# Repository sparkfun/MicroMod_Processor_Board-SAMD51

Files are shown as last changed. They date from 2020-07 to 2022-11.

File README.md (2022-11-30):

SparkFun MicroMod SAMD51 Processor
========================================

SparkFun MicroMod SAMD51 Processor (DEV-16791) (https://www.sparkfun.com/products/16791)

[*SparkFun MicroMod SAMD51 Processor (DEV-16791)*](https://www.sparkfun.com/products/16791)

With a 32-bit ARM Cortex-M4F MCU, the SparkFun MicroMod SAMD51 Processor Board is one powerful microcontroller packaged on a small board! The provides you with an economical and easy to use development platform if you're needing more power with minimal working space. This MicroMod SAMD51 even comes flashed with the same convenient UF2 bootloader like the SAMD51 Thing Plus and the RedBoard Turbo. The MicroMod SAMD51 uses the MicroMod Hardware pinout to easily switch between carrier boards.

The ATSAMD51J20 utilizes a 32-bit ARM Cortex-M4 processor with Floating Point Unit (FPU), running up to 120MHz, up to 1MB of flash memory, up to 256KB of SRAM with ECC, up to 6 SERCOM interfaces, and other features.

Repository Contents
-------------------

* **/Arduino Board Files** - Board definitions for MicroMod SAMD51
* **/Documentation** - Datasheets, additional product information
* **/Hardware** - Eagle design files (.brd, .sch)
* **/Production** - Production panel files (.brd)
* **/uf2-bootloader** - Default firmware

Documentation
--------------
* **[Graphical Datasheet](https://github.com/sparkfun/Graphical_Datasheets/tree/main/Datasheets/SAM51)** - Pinout of the SAMD51 Processor Board
* **[Installing Board Definitions in the Arduino IDE](https://learn.sparkfun.com/tutorials/installing-board-definitions-in-the-arduino-ide)** - Information about installing Arduino Board Files for Arduino
* **[Hookup Guide](https://learn.sparkfun.com/tutorials/micromod-samd51-processor-board-hookup-guide)** - Basic hookup guide

Product Versions
----------------
* [DEV-16791](https://www.sparkfun.com/products/16791)

Version History
---------------
* [v1.3](https://github.com/sparkfun/MicroMod_Processor_Board-SAMD51/tree/v1.3) - Minor update to swap SPI1 lines to the external flash
* [v1.2](https://github.com/sparkfun/MicroMod_Processor_Board-SAMD51/tree/v1.2) - Initial Release 

License Information
-------------------

This product is _**open source**_! 

Please review the LICENSE.md file for license information. 

If you have any questions or concerns on licensing, please contact technical support on our [SparkFun forums](https://forum.sparkfun.com/viewforum.php?f=152).

Distributed as-is; no warranty is given.

- Your friends at SparkFun.

_<COLLABORATION CREDIT>_

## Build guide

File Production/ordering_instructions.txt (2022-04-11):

panel size, 194x70mm
PCB thickness, 0.8mm
number of layers, 4
soldermask color, Red
silkscreen color, White
oz copper, 1oz
finish, ENIG
stencils, top+bottom
pcs per panel, 16
min trace width, 0.1016mm / 0.0040in
min drill size, 0.2000mm / 0.0079in
filename to layer stackup 1/2/3/4: GTL, GL2, GL3, GBL

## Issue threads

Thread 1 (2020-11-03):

Add General/Bus pin definitions to variant.h

adamgarbo, 2020-11-03:
### Subject of the issue
To the best of my knowledge, the SAMD51 Processor board definition appears to be missing (at least) all General/Bus pin definitions in its `variant.h` file.

### Your workbench
* What development board or microcontroller are you using?
  * MicroMod SAMD51 Processor
* What version of hardware or breakout board are you using?
  * MicroMod Data Logging Carrier Board (MMDLCB)
* How is everything being powered?
  * USB-C

### Steps to reproduce
* Connect the SAMD51 Processor to the Data Logging Carrier Board and attempt to compile the MMDLCB Peripheral_Power_Control example:
https://github.com/sparkfun/MicroMod_Data_Logging_Carrier/blob/master/Examples/Peripheral_Power_Control/Peripheral_Power_Control.ino

### Expected behavior
Code should compile as normal.

### Actual behavior
```
Peripheral_Power_Control:5:16: error: 'G0' was not declared in this scope
 int headerCS = G0;
                ^
Peripheral_Power_Control:6:30: error: 'G1' was not declared in this scope
 int peripheralPowerControl = G1;
                              ^
Peripheral_Power_Control:7:25: error: 'G2' was not declared in this scope
 int qwiicPowerControl = G2;
                         ^
exit status 1
```

While I've been able to determine the physical pin numbers on the SAMD51 of G0/G1/G2 power control pins, referencing them directly doesn't work. I believe this most likely has something to do with the SAMD51 being multiplexed.

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

adamgarbo, 2020-11-03:
Ah, of course, I figure it out immediately after! I see now in the schematic how the pins are related: G0/D2, G1/D3, G2/D4
Using these pin definitions, I'm able to control the G1/G2 regulators on the MMDLCB directly.

The question is, should all of the "G"s be included in the variant.h file, or should users simply use their digital pin equivalents? For example, the Artemis variant.h file has all of the General/Bus pins defined. I suppose consistency is key!

```
#define G0 16
#define G1 33
#define G2 34
#define G3 27
#define G4 28
#define G5 29
#define G6 14
#define G7 15
#define G8 3
#define G9 ADC_DIFF_NEG
#define G10 ADC_DIFF_POS
#define G11 11
```

Cheers,
Adam

edspark, 2020-11-04:
Ah this is a great idea, something I had considered and not sure why I didn't do. Thanks for bringing it back to my attention - I'll roll it into a release soon.

edspark, 2020-11-04:
Thanks for the issue, the `#defines` for the relevant pins on the SAMD51 Micromod have been added to our Arduino Boards repository. I did not add ADC related `#defines` as they are not physically routed in such a way on the SAMD51 Micromod. I've also added keywords to that repository so that they're highlighted when you use the general pin nomenclature: `G0`, `G1`, etc... You can find these changes in the [1.7.8 release](https://github.com/sparkfun/Arduino_Boards/commit/cf6146e5421a28d8b91430474607ebbde78a0eef).

Closed 2020-11-04.

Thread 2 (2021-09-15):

Swapped SPI1 lines

shale-bridge, 2021-09-15:
### Swapped SPI1 lines
External W25Q128 flash CIPO/COPI lines are swapped, so flash is unusable with SPI.

### Equipment
* SAMD51 MicroMod v1.2
* ATP (All-The-Pins) v1.1 breakout
* Custom motherboard

### Workaround
Swapping the CIPO/COPI lines in software and manually (bit-banging) data to/from the flash chip.

edspark, 2021-09-15:
Thanks for the issue, a fix is on the way. I'll update in a few weeks when the new version is ready. When that happens feel free to reach out to SparkFun's customer service to get a replacement.

stonehippo, 2021-11-10:
Any update on this @edspark? Would love to get a board with working external flash.

shale-bridge, 2021-11-10:
Looks like all SAMD51 chips are on backorder until well into next year (Estimates at Nov/Dec 2022 before any stock becomes available).

shale-bridge, 2021-11-10:
@stonehippo If you already have a SAMD51 MicroMod, I made a library that works with the layout error through software bit-banging.

[SAMD51 Bit Bang Library](https://github.com/shale-bridge/samd51-micromod-bitbang)

stonehippo, 2021-11-10:
Thanks, @shale-bridge, I saw that, and I’ll probably use it for Arduino until we can get updated boards.

I had ported CircuitPython to this board, but not having the external flash makes that sorta nasty. I was going to look into making a personal patch to try using your idea to enable bitbang serial for this board there, too.

edspark, 2021-11-10:
Hello everyone, yes it took a bit longer for the boards to arrive but they're expected sometime this week. After they received it will take a week or two to get back on storefront.

stonehippo, 2021-12-01:
@edspark I got a back in stock notification on the module (though the site is still showing it as backorder). Has the new version arrived? If so, what's the best way to exchange the previous version?

edspark, 2021-12-07:
Hey @stonehippo, I do see we have the PCBs in stock and I'm currently inquiring as to when they will be moved through production to get them back onto the website. The best way is to exchange your old one is go through the process [listed here](https://www.sparkfun.com/returns).

edspark, 2022-04-11:
I've finally merged in the latest branch with the fix. I've tested the lines using [SparkFun's SPI SerialFlash library](https://github.com/sparkfun/SparkFun_SPI_SerialFlash_Arduino_Library) and I can now finally close this issue.

stonehippo, 2022-04-11:
@edspark could you share the test code you used? I want to jump on fixing the support in CircuitPython and that will help.

edspark, 2022-04-12:
Example here in the SparkFun SPI SerialFlash Library:
https://github.com/sparkfun/SparkFun_SPI_SerialFlash_Arduino_Library/blob/main/examples/SPI_Flash_Example/SPI_Flash_Example.ino

stonehippo, 2022-04-12:
Thanks, I was hoping for the exact changes you made to that example (i.e. did you need to set the HOLD and WP pins high, and what pins did you use, etc). If you used it as-is, great!

stonehippo, 2022-04-12:
Thanks!

stonehippo, 2022-04-19:
Thanks for the support, @edspark! I was able finally able to get the flash working with Circuitpython.

Closed 2022-04-11.

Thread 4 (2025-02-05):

Self-build binary for 'sparkfun-samd51-micromod' is not working

walx666, 2025-02-05:
It is possible to build the bootloader-binary for the 'sparkfun-samd51-micromod' board, but the bootloader-binary is not working!

I was not able to build a working bootloader-binary with the latest sources from
https://github.com/adafruit/uf2-samdx1 or https://github.com/microsoft/uf2-samdx1
nor any older commit i tried…

...also tried to build the bootloader with the commit 'df89a1f', but that seems to not have the changes you may made (dirty build).

I also have an 'sparkfun-samd51-thingplus' and was able to build a working bootloader with the same evnrionment.

## Symptoms
The LED is not flashing as it should and the usb-flashdrive nor the CDC-device is not appearing in the os (windows in my case)

## Hardware
- micromod-atp
- sparkfun-samd51-micromod (ATSAMD51J20A with chip revision A and D)
- sparkfun-samd51-thingplus

## Build Evnrionment:
- windows 11 pro 24H2
	- arm-none-eabi-gcc.exe (GNU Arm Embedded Toolchain 10.3-2021.10) 10.3.1 20210824 (release)
- debian12 (wsl)
	- arm-none-eabi-gcc (GNU Arm Embedded Toolchain 10.3-2021.10) 10.3.1 20210824 (release)

---

The board has this INFO_UF2.TXT (only as binary and board-definition avaliable):
```
UF2 Bootloader v3.4.0-65-gdf89a1f-dirty SFHWRO
Model: SparkFun MicroMod SAMD51
Board-ID: SAMD51J20A-SparkFun-MicroMod
```

I've made a board, that integrates the 'sparkfun-samd51-micromod' board - so i'd like to have the improvements of a newer build / release, beacuse sometimes the flash gets corrupted or the board does not start after powerup (see https://github.com/adafruit/uf2-samdx1/issues/217) -
also i want to make little changes to the bootloader for my needs.

So please let me know, what you have changed to the bootloader code or board-definition, so that it works - or release a working codebase.

Best would be to fork the uf2-samdx1 and release it for the public - or even better upstream the changes.

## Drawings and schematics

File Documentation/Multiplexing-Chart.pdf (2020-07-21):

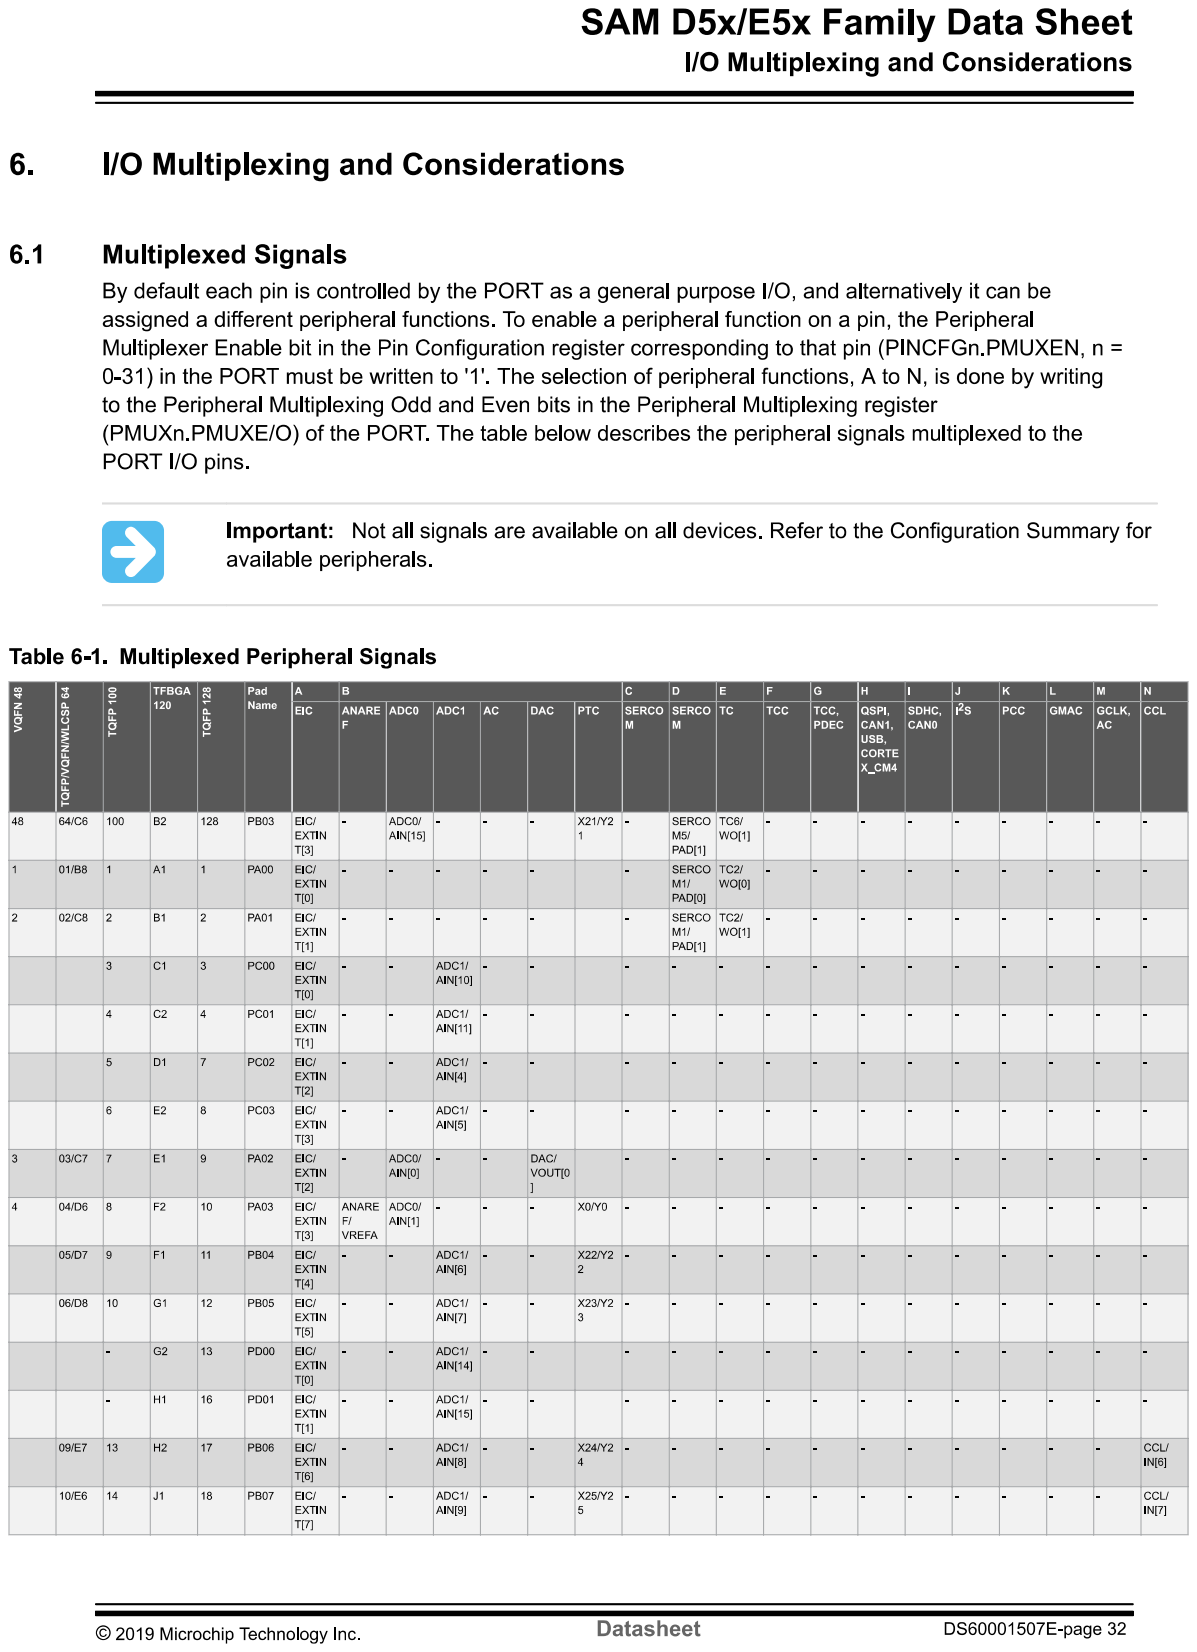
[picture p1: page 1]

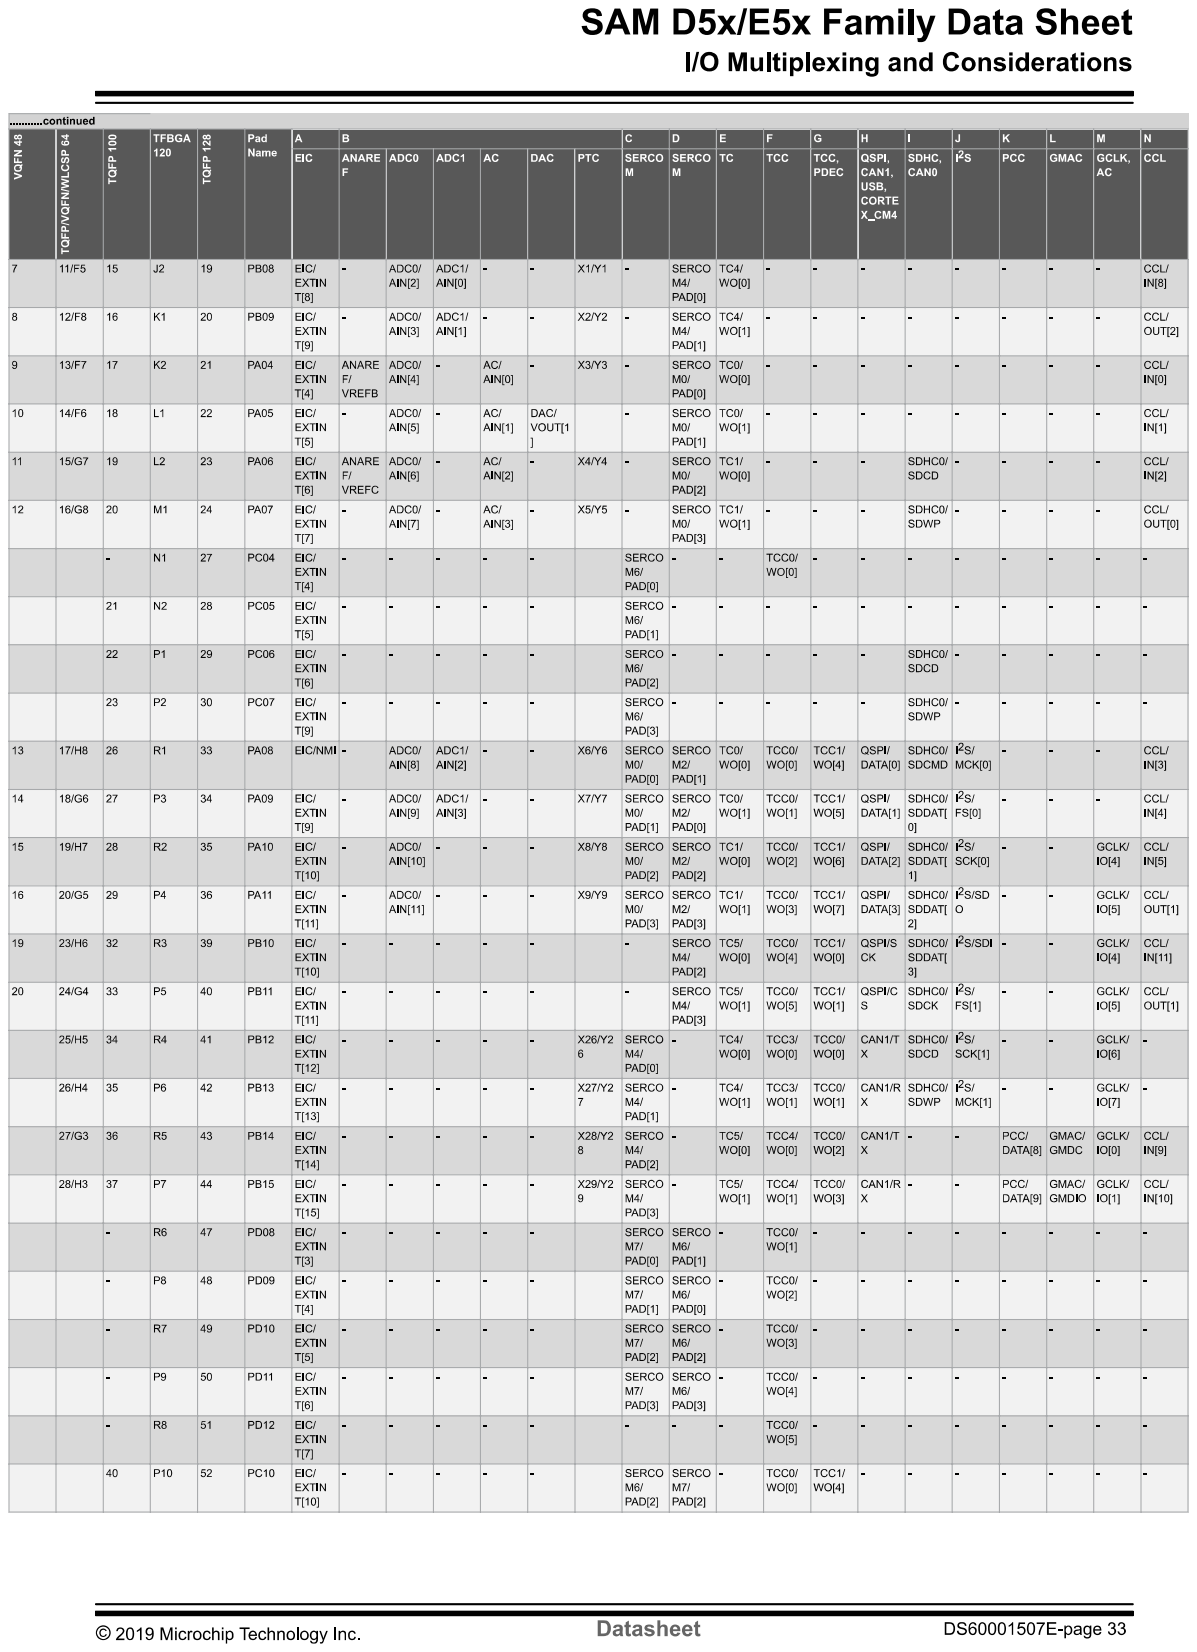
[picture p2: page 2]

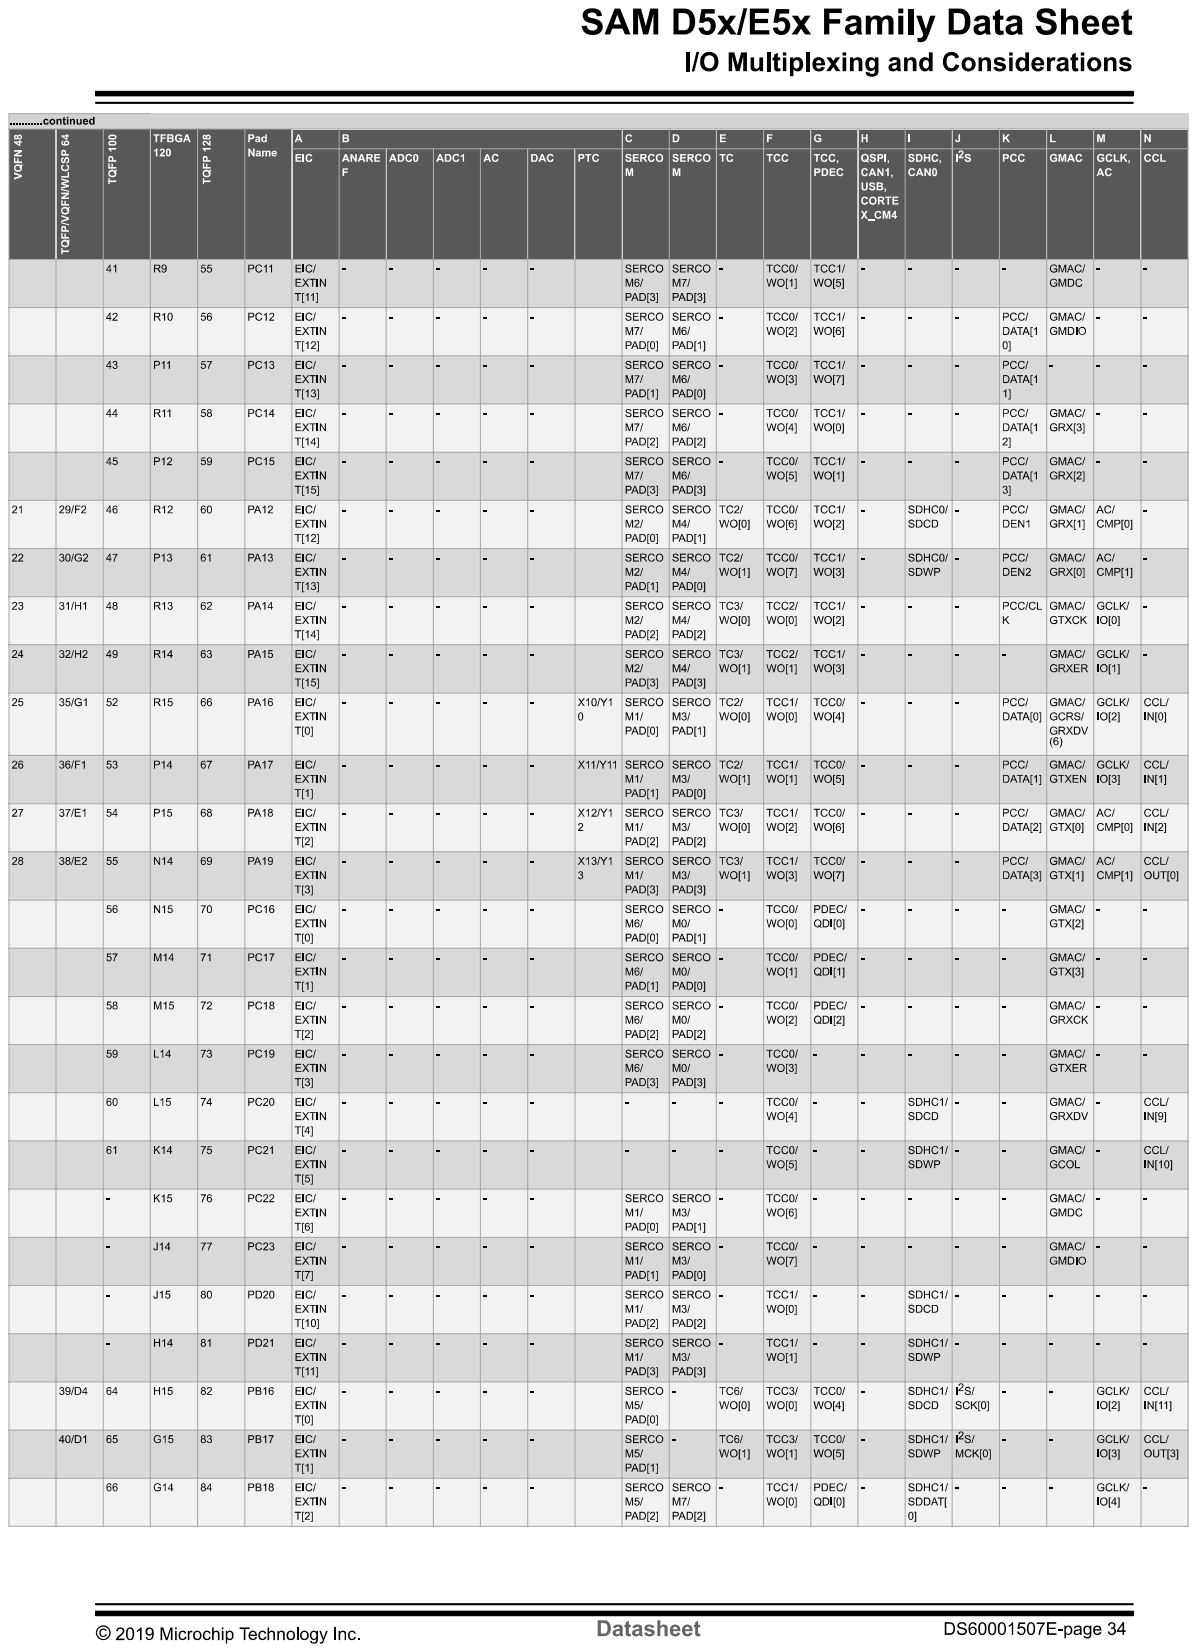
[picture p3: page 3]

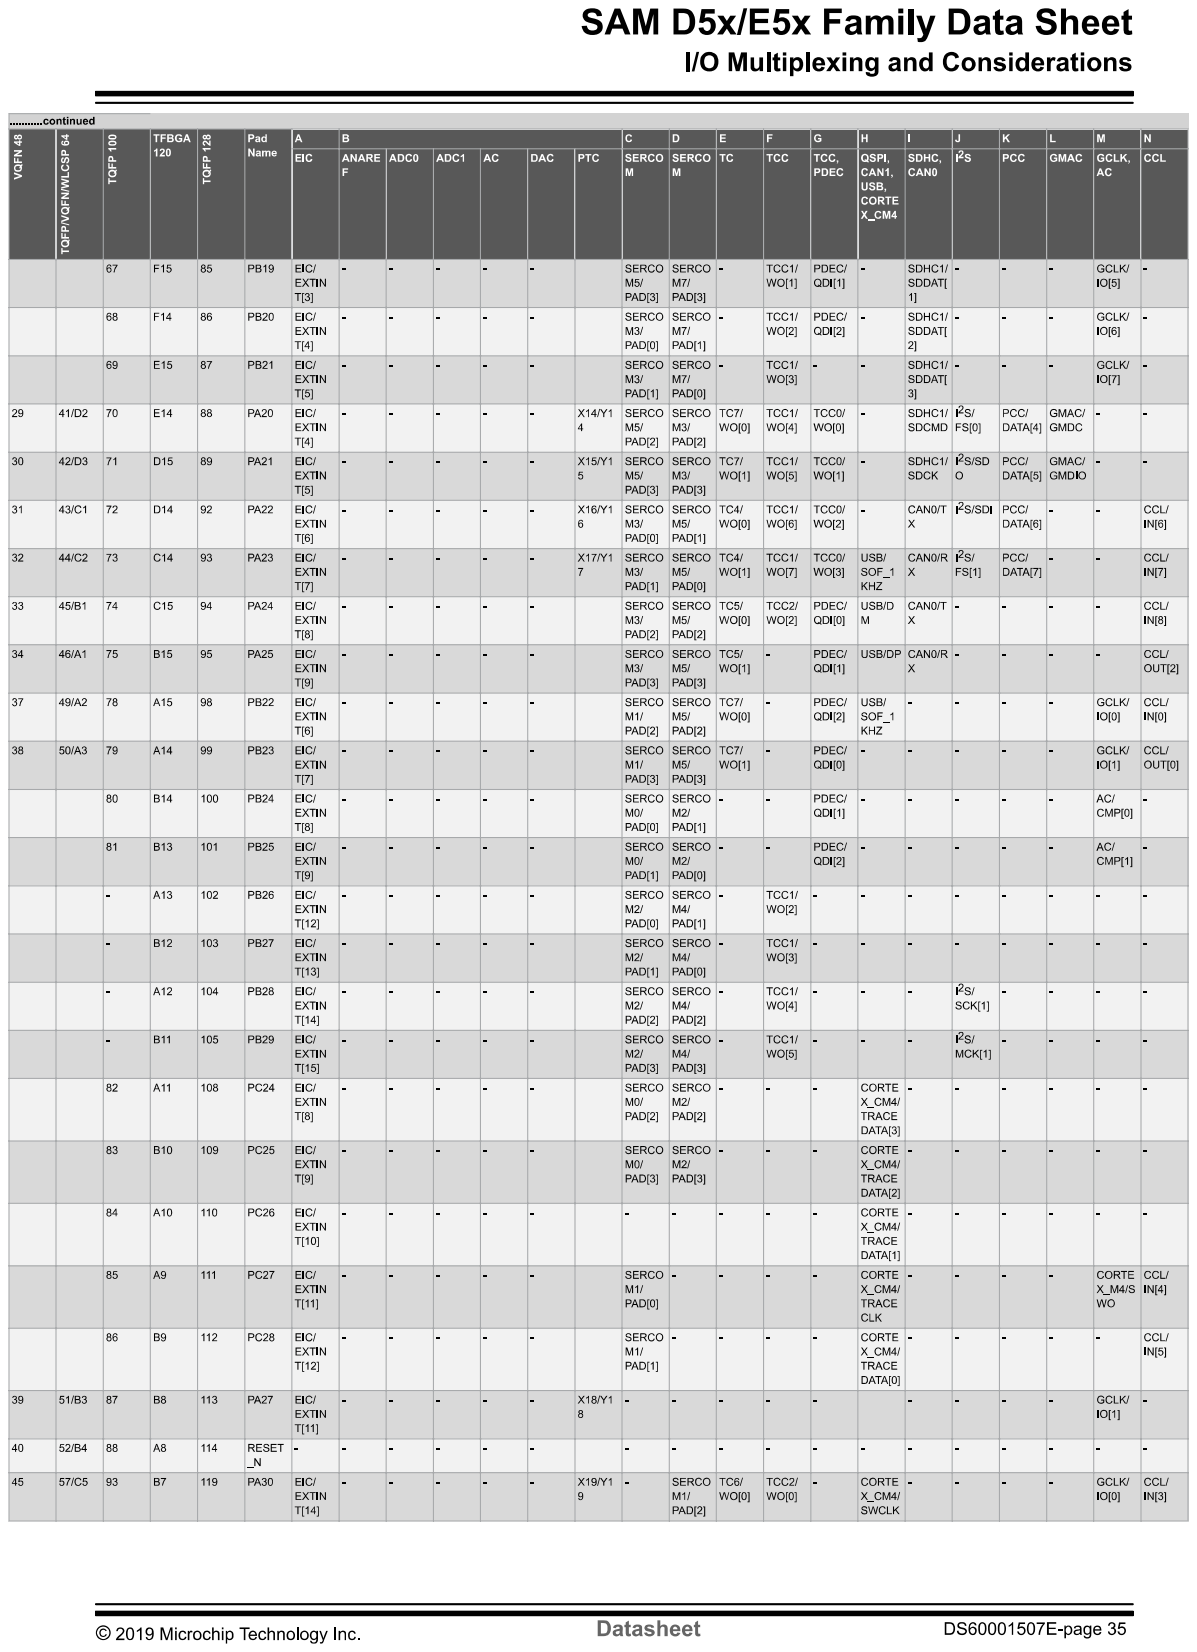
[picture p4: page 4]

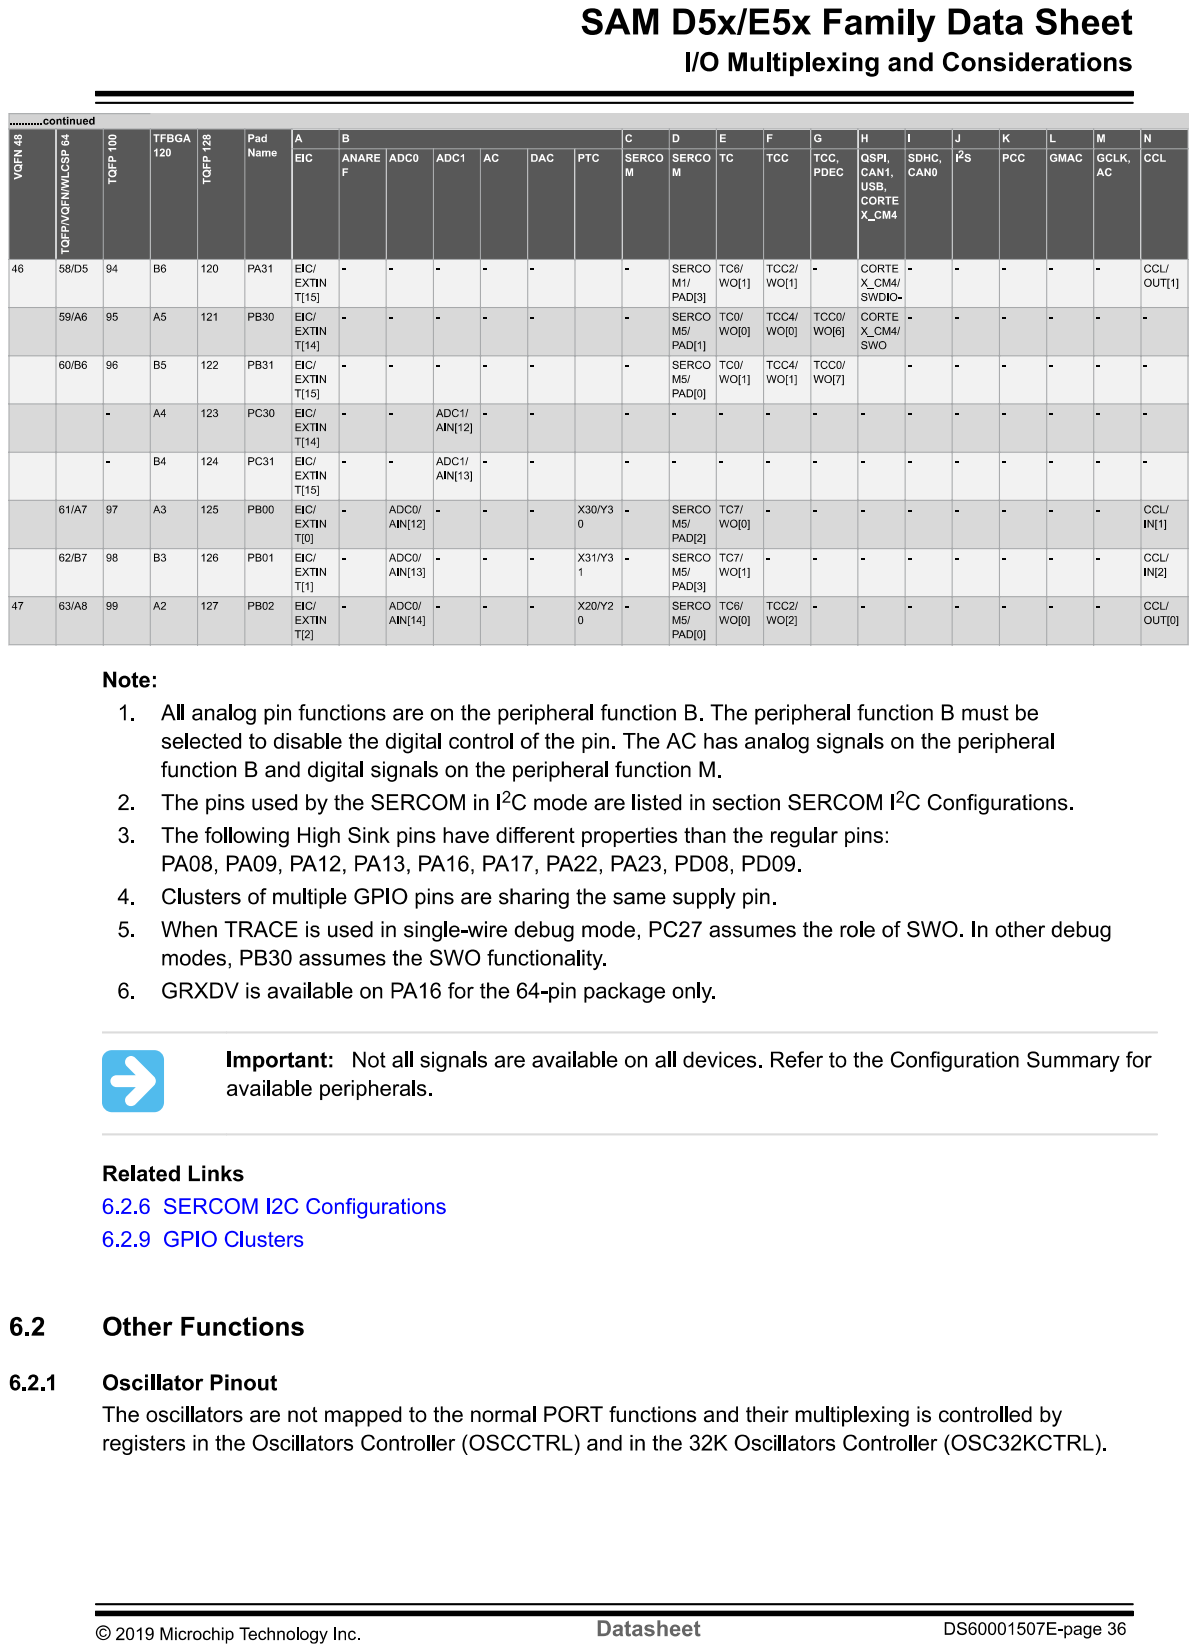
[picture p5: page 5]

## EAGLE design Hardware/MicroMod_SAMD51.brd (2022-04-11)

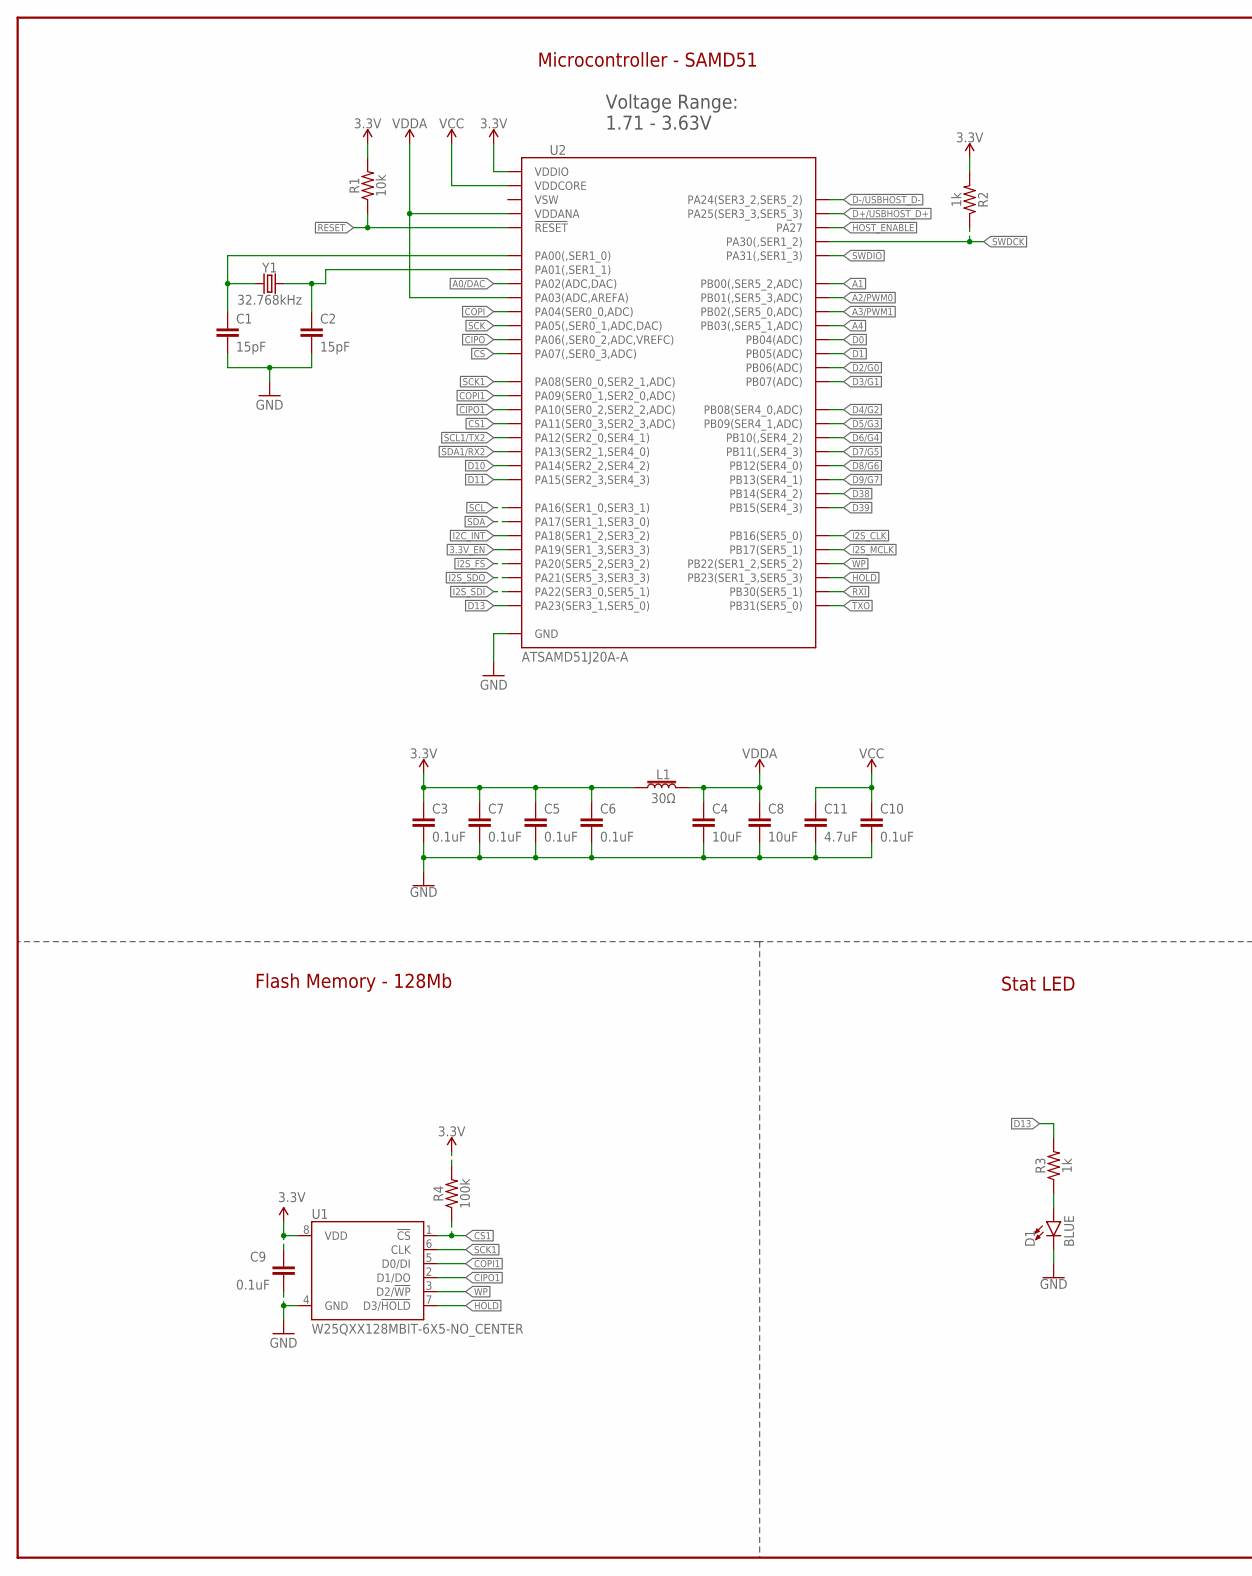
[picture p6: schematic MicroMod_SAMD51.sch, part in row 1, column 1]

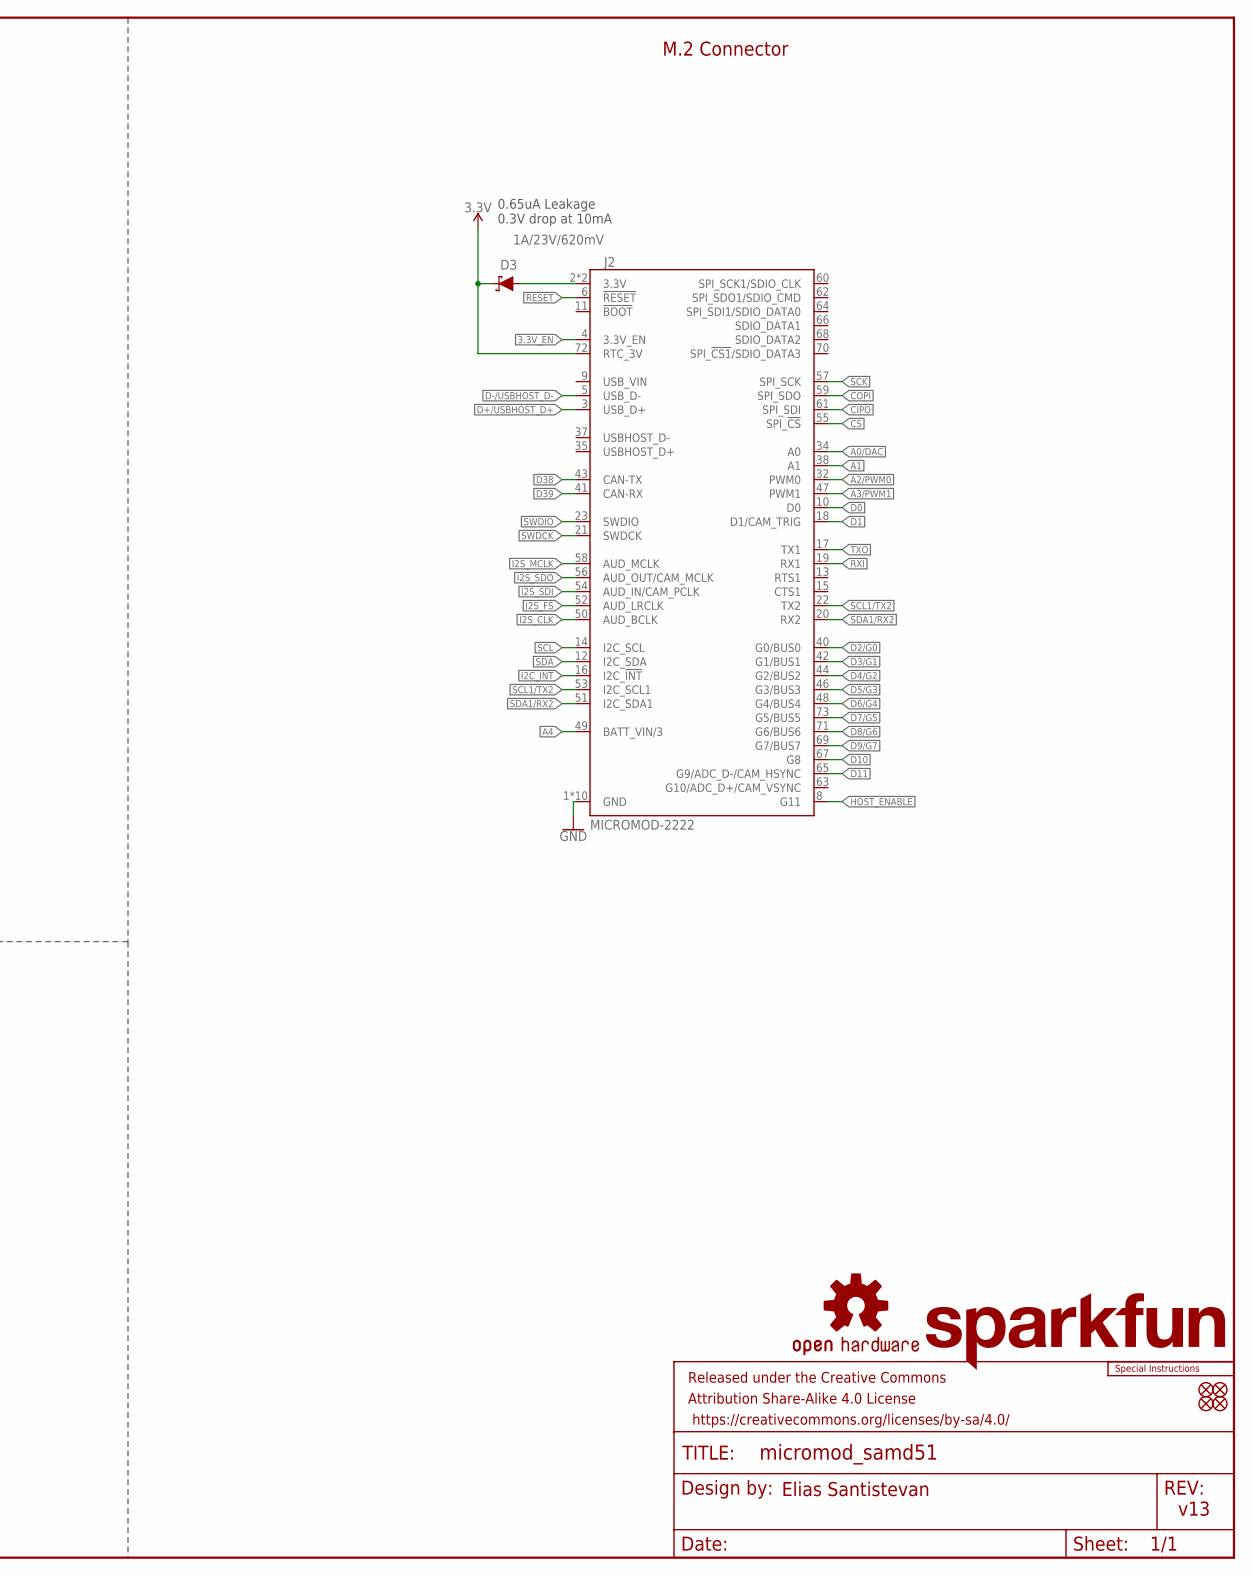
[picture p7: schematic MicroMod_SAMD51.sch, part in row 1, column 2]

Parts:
C1, C2: 15pF; 0402-TIGHT
C3, C5, C6, C7, C9, C10: 0.1uF; 0402-TIGHT
C4, C8: 10uF; 0402-TIGHT
C11: 4.7uF; 0402-TIGHT
D1: BLUE; LED-0603
D3: 1A/23V/620mV; SOD-323
FD5, FD6, FD7, FD8: FIDUCIALUFIDUCIAL; FIDUCIAL-MICRO
FRAME2: FRAME-LEDGER; CREATIVE_COMMONS
J2: MICROMOD-2222; M.2-CARD-E-22
L1: 30Ω; 0402-TIGHT
LOGO2: OSHW-LOGOMINI; OSHW-LOGO-MINI
LOGO5: SPECIAL_INSTRUCTIONS-ORDERING; ORDERING_INSTRUCTIONS
LOGO6: SFE_LOGO_NAME.1_INCH; SFE_LOGO_NAME_.1
R1: 10k; 0402-TIGHT
R2, R3: 1k; 0402-TIGHT
R4: 100k; 0402-TIGHT
U1: W25QXX128MBIT-6X5-NO_CENTER; WSON-8-6X5-NO_CENTERPAD
U2: ATSAMD51J20A-A; TQFP64
Y1: 32.768kHz; CRYSTAL-SMD-3.2X1.5MM

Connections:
3.3V: C3.1, C5.1, C6.1, C7.1, C9.1, D3.C, J2.72 (RTC_3V), L1.1, R1.2, R2.2, R4.2, U1.8 (VDD), U2.21 (VDDIO), U2.34 (VDDIO), U2.48 (VDDIO), U2.56 (VDDIO)
3.3V_EN: J2.4 (3.3V_EN), U2.38 (PA19(SER1_3,SER3_3))
3.3V_IN: D3.A, J2.2 (3.3V), J2.74 (3.3V)
!CS: J2.55 (SPI_!CS!), U2.16 (PA07(,SER0_3,ADC))
!CS1!: R4.1, U1.1 (!CS!), U2.20 (PA11(SER0_3,SER2_3,ADC))
!HOLD!: U1.7 (D3/!HOLD!), U2.50 (PB23(SER1_3,SER5_3))
!RESET: J2.6 (!RESET!), R1.1, U2.52 (!RESET)
!WP!: U1.3 (D2/!WP!), U2.49 (PB22(SER1_2,SER5_2))
A0/DAC: J2.34 (A0), U2.3 (PA02(ADC,DAC))
A1: J2.38 (A1), U2.61 (PB00(,SER5_2,ADC))
A2/PWM0: J2.32 (PWM0), U2.62 (PB01(,SER5_3,ADC))
A3/PWM1: J2.47 (PWM1), U2.63 (PB02(,SER5_0,ADC))
A4: J2.49 (BATT_VIN/3), U2.64 (PB03(,SER5_1,ADC))
CIPO: J2.61 (SPI_SDI), U2.15 (PA06(,SER0_2,ADC,VREFC))
CIPO1: U1.2 (D1/DO), U2.19 (PA10(SER0_2,SER2_2,ADC))
COPI: J2.59 (SPI_SDO), U2.13 (PA04(SER0_0,ADC))
COPI1: U1.5 (D0/DI), U2.18 (PA09(SER0_1,SER2_0,ADC))
D0: J2.10 (D0), U2.5 (PB04(ADC))
D1: J2.18 (D1/CAM_TRIG), U2.6 (PB05(ADC))
D2/G0: J2.40 (G0/BUS0), U2.9 (PB06(ADC))
D3/G1: J2.42 (G1/BUS1), U2.10 (PB07(ADC))
D4/G2: J2.44 (G2/BUS2), U2.11 (PB08(SER4_0,ADC))
D5/G3: J2.46 (G3/BUS3), U2.12 (PB09(SER4_1,ADC))
D6/G4: J2.48 (G4/BUS4), U2.23 (PB10(,SER4_2))
D7/G5: J2.73 (G5/BUS5), U2.24 (PB11(,SER4_3))
D8/G6: J2.71 (G6/BUS6), U2.25 (PB12(SER4_0))
D9/G7: J2.69 (G7/BUS7), U2.26 (PB13(SER4_1))
D10: J2.67 (G8), U2.31 (PA14(SER2_2,SER4_2))
D11: J2.65 (G9/ADC_D-/CAM_HSYNC), U2.32 (PA15(SER2_3,SER4_3))
D13: R3.2, U2.44 (PA23(SER3_1,SER5_0))
D38: J2.43 (CAN-TX), U2.27 (PB14(SER4_2))
D39: J2.41 (CAN-RX), U2.28 (PB15(SER4_3))
D+/USBHOST_D+: J2.3 (USB_D+), U2.46 (PA25(SER3_3,SER5_3))
D-/USBHOST_D-: J2.5 (USB_D-), U2.45 (PA24(SER3_2,SER5_2))
GND: C1.2, C2.2, C3.2, C4.2, C5.2, C6.2, C7.2, C8.2, C9.2, C10.2, C11.2, D1.C, J2.1 (GND), J2.7 (GND), J2.33 (GND), J2.36 (GND), J2.39 (GND), J2.45 (GND), J2.75 (GND), J2.GND1 (GND), J2.GND2 (GND), J2.GND3 (GND), U1.4 (GND), U2.7 (GND), U2.22 (GND), U2.33 (GND), U2.47 (GND), U2.54 (GND)
HOST_ENABLE: J2.8 (G11), U2.51 (PA27)
I2C_!INT!: J2.16 (I2C_!INT!), U2.37 (PA18(SER1_2,SER3_2))
I2S_CLK: J2.50 (AUD_BCLK), U2.39 (PB16(SER5_0))
I2S_FS: J2.52 (AUD_LRCLK), U2.41 (PA20(SER5_2,SER3_2))
I2S_MCLK: J2.58 (AUD_MCLK), U2.40 (PB17(SER5_1))
I2S_SDI: J2.54 (AUD_IN/CAM_PCLK), U2.43 (PA22(SER3_0,SER5_1))
I2S_SDO: J2.56 (AUD_OUT/CAM_MCLK), U2.42 (PA21(SER5_3,SER3_3))
unnamed: D1.A, R3.1
RXI: J2.19 (RX1), U2.59 (PB30(SER5_1))
SCK: J2.57 (SPI_SCK), U2.14 (PA05(,SER0_1,ADC,DAC))
SCK1: U1.6 (CLK), U2.17 (PA08(SER0_0,SER2_1,ADC))
SCL: J2.14 (I2C_SCL), U2.35 (PA16(SER1_0,SER3_1))
SCL1/TX2: J2.22 (TX2), J2.53 (I2C_SCL1), U2.29 (PA12(SER2_0,SER4_1))
SDA: J2.12 (I2C_SDA), U2.36 (PA17(SER1_1,SER3_0))
SDA1/RX2: J2.20 (RX2), J2.51 (I2C_SDA1), U2.30 (PA13(SER2_1,SER4_0))
SWDCK: J2.21 (SWDCK), R2.1, U2.57 (PA30(,SER1_2))
SWDIO: J2.23 (SWDIO), U2.58 (PA31(,SER1_3))
TXO: J2.17 (TX1), U2.60 (PB31(SER5_0))
VCC: C10.1, C11.1, U2.53 (VDDCORE)
VDDA: C4.1, C8.1, L1.2, U2.4 (PA03(ADC,AREFA)), U2.8 (VDDANA)
XIN32: C1.1, U2.1 (PA00(,SER1_0)), Y1.P$1 (1)
XOUT32: C2.1, U2.2 (PA01(,SER1_1)), Y1.P$2 (2)

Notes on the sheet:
v13
M.2 Connector
Microcontroller - SAMD51
Flash Memory - 128Mb
Stat LED
Elias Santistevan
0.65uA Leakage 0.3V drop at 10mA
Voltage Range: 1.71 - 3.63V

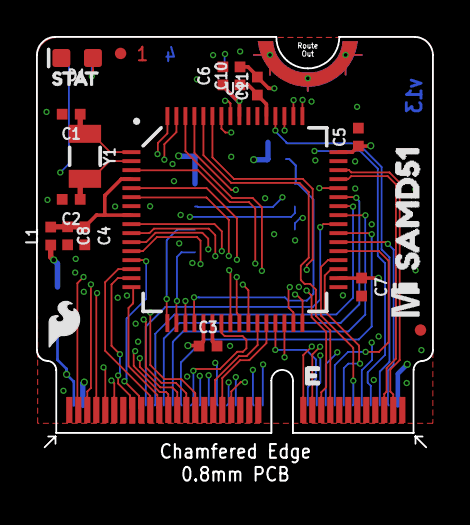
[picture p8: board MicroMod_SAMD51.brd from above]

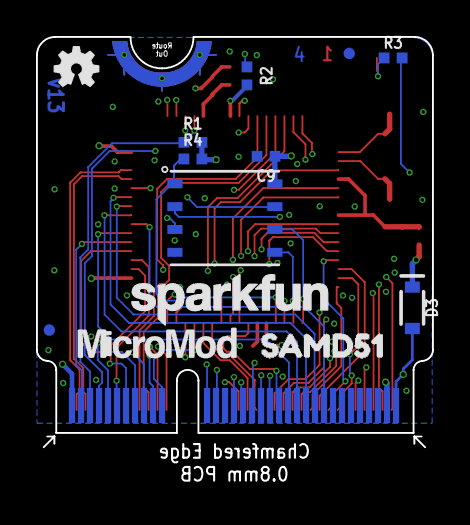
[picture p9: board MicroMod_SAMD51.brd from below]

Board: 4 copper layers, 22.0 x 22.8 mm, 36 parts (13 on the bottom side), 57 nets.

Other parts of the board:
U$1: MICROMOD_MI_LOGO_.35
U$4: MICROMOD_LOGO_.35
U$5, U$6: SAMD510
U$7: SFE_LOGO_FLAME_.1
U$8: STAT0

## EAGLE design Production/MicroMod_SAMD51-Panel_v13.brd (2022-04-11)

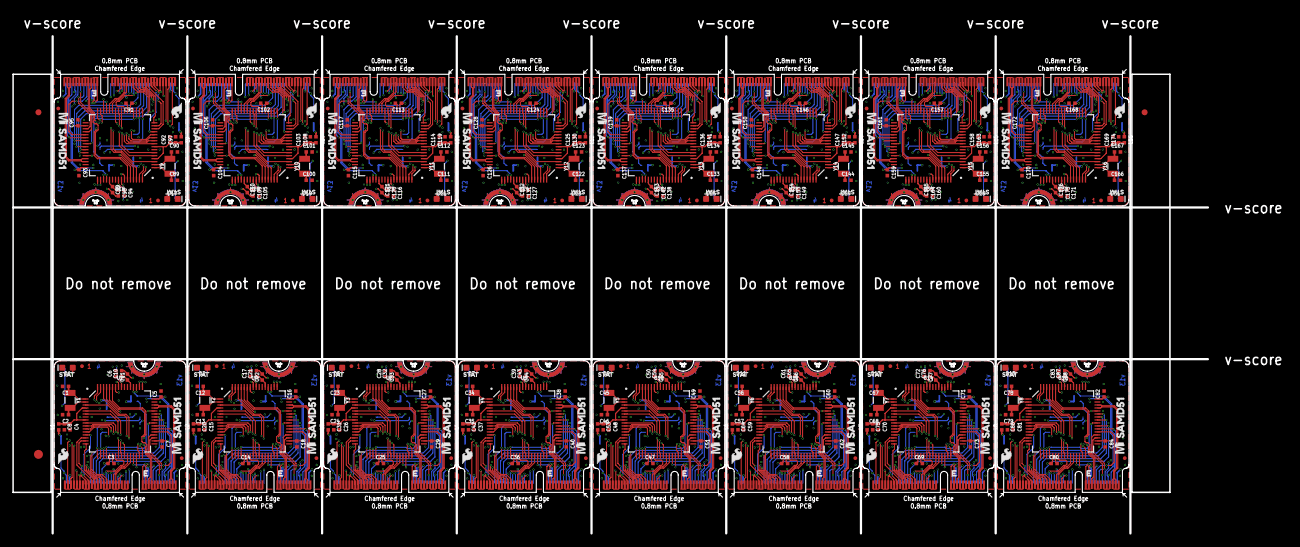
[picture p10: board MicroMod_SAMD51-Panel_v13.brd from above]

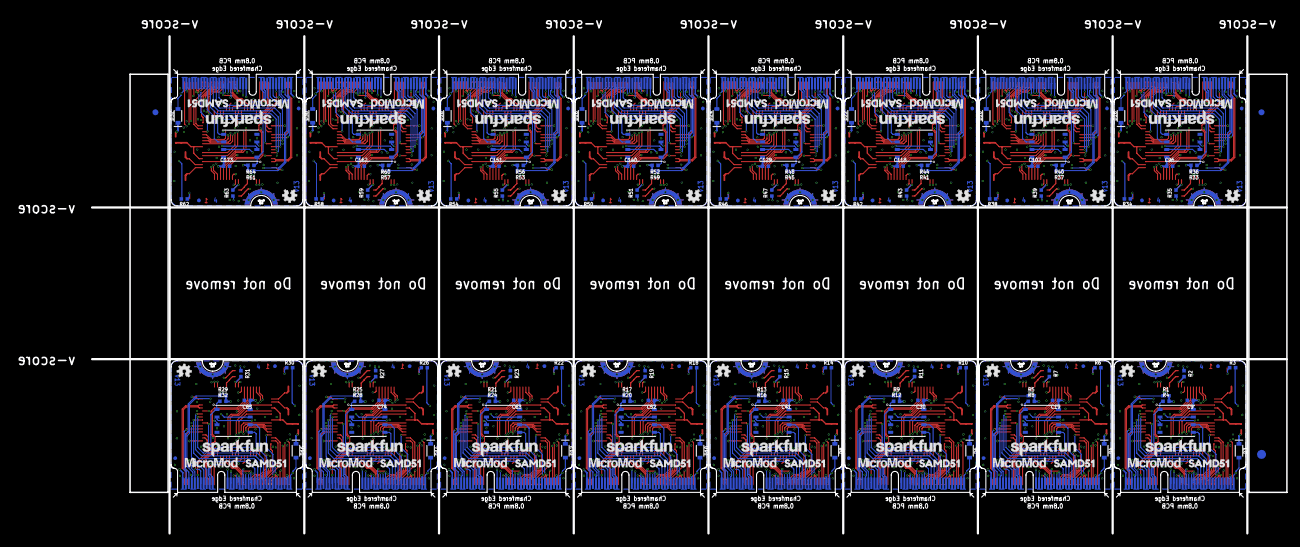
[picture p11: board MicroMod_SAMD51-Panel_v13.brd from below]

Board: 4 copper layers, 199.6 x 83.1 mm, 550 parts (211 on the bottom side), 912 nets.

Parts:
C1, C2, C12, C13, C23, C24, C34, C35, C45, C46, C56, C57, C67, C68, C78, C79, C89, C90, C100, C101, C111, C112, C122, C123, C133, C134, C144, C145, C155, C156, C166, C167: 15pF; 0402-TIGHT
C3, C5, C6, C7, C9, C10, C14, C16, C17, C18, C19, C21, C25, C27, C28, C29, C30, C32, C36, C38, C39, C40, C41, C43, C47, C49, C50, C51, C52, C54, C58, C60, C61, C62, C63, C65, C69, C71, C72, C73, C74, C76, C80, C82, C83, C84, C85, C87, C91, C93, C94, C95, C96, C98, C102, C104, C105, C106, C107, C109, C113, C115, C116, C117, C118, C120, C124, C126, C127, C128, C129, C131, C135, C137, C138, C139, C140, C142, C146, C148, C149, C150, C151, C153, C157, C159, C160, C161, C162, C164, C168, C170, C171, C172, C173, C175: 0.1uF; 0402-TIGHT
C4, C8, C15, C20, C26, C31, C37, C42, C48, C53, C59, C64, C70, C75, C81, C86, C92, C97, C103, C108, C114, C119, C125, C130, C136, C141, C147, C152, C158, C163, C169, C174: 10uF; 0402-TIGHT
C11, C22, C33, C44, C55, C66, C77, C88, C99, C110, C121, C132, C143, C154, C165, C176: 4.7uF; 0402-TIGHT
D1, D2, D5, D7, D9, D11, D13, D15, D17, D19, D21, D23, D25, D27, D29, D31: BLUE; LED-0603
D3, D4, D6, D8, D10, D12, D14, D16, D18, D20, D22, D24, D26, D28, D30, D32: 1A/23V/620mV; SOD-323
E$1, E$2, E$3, E$4: FIDUCIAL-1X2
E$5, E$6: FIDUCIAL-1.5X3
FD1, FD2, FD3, FD4, FD5, FD6, FD7, FD8, FD9, FD10, FD11, FD12, FD13, FD14, FD15, FD16, FD17, FD18, FD19, FD20, FD21, FD22, FD23, FD24, FD25, FD26, FD27, FD28, FD29, FD30, FD31, FD32, FD33, FD34, FD35, FD36, FD37, FD38, FD39, FD40, FD41, FD42, FD43, FD44, FD45, FD46, FD47, FD48, FD49, FD50, FD51, FD52, FD53, FD54, FD55, FD56, FD57, FD58, FD59, FD60, FD61, FD62, FD63, FD64: FIDUCIALUFIDUCIAL; FIDUCIAL-MICRO
J1, J2, J3, J4, J5, J6, J7, J8, J9, J10, J11, J12, J13, J14, J15, J16: MICROMOD-2222; M.2-CARD-E-22
L1, L2, L3, L4, L5, L6, L7, L8, L9, L10, L11, L12, L13, L14, L15, L16: 30Ω; 0402-TIGHT
LOGO1, LOGO2, LOGO4, LOGO7, LOGO9, LOGO11, LOGO13, LOGO15, LOGO17, LOGO19, LOGO21, LOGO23, LOGO25, LOGO27, LOGO29, LOGO31: OSHW-LOGOMINI; OSHW-LOGO-MINI
LOGO3, LOGO5, LOGO6, LOGO8, LOGO10, LOGO12, LOGO14, LOGO16, LOGO18, LOGO20, LOGO22, LOGO24, LOGO26, LOGO28, LOGO30, LOGO32: SFE_LOGO_NAME.1_INCH; SFE_LOGO_NAME_.1
R1, R5, R9, R13, R17, R21, R25, R29, R33, R37, R41, R45, R49, R53, R57, R61: 10k; 0402-TIGHT
R2, R3, R6, R7, R10, R11, R14, R15, R18, R19, R22, R23, R26, R27, R30, R31, R34, R35, R38, R39, R42, R43, R46, R47, R50, R51, R54, R55, R58, R59, R62, R63: 1k; 0402-TIGHT
R4, R8, R12, R16, R20, R24, R28, R32, R36, R40, R44, R48, R52, R56, R60, R64: 100k; 0402-TIGHT
U1, U3, U5, U7, U9, U11, U13, U15, U17, U19, U21, U23, U25, U27, U29, U31: W25QXX128MBIT-6X5-NO_CENTER; WSON-8-6X5-NO_CENTERPAD
U2, U4, U6, U8, U10, U12, U14, U16, U18, U20, U22, U24, U26, U28, U30, U32: ATSAMD51J20A-A; TQFP64
U$1, U$11, U$17, U$23, U$29, U$35, U$41, U$47, U$53, U$59, U$65, U$71, U$77, U$83, U$89, U$95: MICROMOD_MI_LOGO_.35
U$2, U$3, U$5, U$6, U$13, U$14, U$19, U$20, U$25, U$26, U$31, U$32, U$37, U$38, U$43, U$44, U$49, U$50, U$55, U$56, U$61, U$62, U$67, U$68, U$73, U$74, U$79, U$80, U$85, U$86, U$91, U$92: SAMD510
U$4, U$12, U$18, U$24, U$30, U$36, U$42, U$48, U$54, U$60, U$66, U$72, U$78, U$84, U$90, U$96: MICROMOD_LOGO_.35
U$7, U$9, U$15, U$21, U$27, U$33, U$39, U$45, U$51, U$57, U$63, U$69, U$75, U$81, U$87, U$93: SFE_LOGO_FLAME_.1
U$8, U$10, U$16, U$22, U$28, U$34, U$40, U$46, U$52, U$58, U$64, U$70, U$76, U$82, U$88, U$94: STAT0
Y1, Y2, Y3, Y4, Y5, Y6, Y7, Y8, Y9, Y10, Y11, Y12, Y13, Y14, Y15, Y16: 32.768kHz; CRYSTAL-SMD-3.2X1.5MM

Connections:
3.3V: C3.1, C5.1, C6.1, C7.1, C9.1, D3.C, J2.72, L1.1, R1.2, R2.2, R4.2, U1.8, U2.21, U2.34, U2.48, U2.56
3.3V1: C14.1, C16.1, C17.1, C18.1, C19.1, D4.C, J1.72, L2.1, R5.2, R7.2, R8.2, U3.8, U4.21, U4.34, U4.48, U4.56
3.3V2: C25.1, C27.1, C28.1, C29.1, C30.1, D6.C, J3.72, L3.1, R9.2, R11.2, R12.2, U5.8, U6.21, U6.34, U6.48, U6.56
3.3V3: C36.1, C38.1, C39.1, C40.1, C41.1, D8.C, J4.72, L4.1, R13.2, R15.2, R16.2, U7.8, U8.21, U8.34, U8.48, U8.56
3.3V4: C47.1, C49.1, C50.1, C51.1, C52.1, D10.C, J5.72, L5.1, R17.2, R19.2, R20.2, U9.8, U10.21, U10.34, U10.48, U10.56
3.3V5: C58.1, C60.1, C61.1, C62.1, C63.1, D12.C, J6.72, L6.1, R21.2, R23.2, R24.2, U11.8, U12.21, U12.34, U12.48, U12.56
3.3V6: C69.1, C71.1, C72.1, C73.1, C74.1, D14.C, J7.72, L7.1, R25.2, R27.2, R28.2, U13.8, U14.21, U14.34, U14.48, U14.56
3.3V7: C80.1, C82.1, C83.1, C84.1, C85.1, D16.C, J8.72, L8.1, R29.2, R31.2, R32.2, U15.8, U16.21, U16.34, U16.48, U16.56
3.3V8: C91.1, C93.1, C94.1, C95.1, C96.1, D18.C, J9.72, L9.1, R33.2, R35.2, R36.2, U17.8, U18.21, U18.34, U18.48, U18.56
3.3V9: C102.1, C104.1, C105.1, C106.1, C107.1, D20.C, J10.72, L10.1, R37.2, R39.2, R40.2, U19.8, U20.21, U20.34, U20.48, U20.56
3.3V10: C113.1, C115.1, C116.1, C117.1, C118.1, D22.C, J11.72, L11.1, R41.2, R43.2, R44.2, U21.8, U22.21, U22.34, U22.48, U22.56
3.3V11: C124.1, C126.1, C127.1, C128.1, C129.1, D24.C, J12.72, L12.1, R45.2, R47.2, R48.2, U23.8, U24.21, U24.34, U24.48, U24.56
3.3V12: C135.1, C137.1, C138.1, C139.1, C140.1, D26.C, J13.72, L13.1, R49.2, R51.2, R52.2, U25.8, U26.21, U26.34, U26.48, U26.56
3.3V13: C146.1, C148.1, C149.1, C150.1, C151.1, D28.C, J14.72, L14.1, R53.2, R55.2, R56.2, U27.8, U28.21, U28.34, U28.48, U28.56
3.3V14: C157.1, C159.1, C160.1, C161.1, C162.1, D30.C, J15.72, L15.1, R57.2, R59.2, R60.2, U29.8, U30.21, U30.34, U30.48, U30.56
3.3V15: C168.1, C170.1, C171.1, C172.1, C173.1, D32.C, J16.72, L16.1, R61.2, R63.2, R64.2, U31.8, U32.21, U32.34, U32.48, U32.56
3.3V_EN: J2.4, U2.38
3.3V_EN1: J1.4, U4.38
3.3V_EN2: J3.4, U6.38
3.3V_EN3: J4.4, U8.38
3.3V_EN4: J5.4, U10.38
3.3V_EN5: J6.4, U12.38
3.3V_EN6: J7.4, U14.38
3.3V_EN7: J8.4, U16.38
3.3V_EN8: J9.4, U18.38
3.3V_EN9: J10.4, U20.38
3.3V_EN10: J11.4, U22.38
3.3V_EN11: J12.4, U24.38
3.3V_EN12: J13.4, U26.38
3.3V_EN13: J14.4, U28.38
3.3V_EN14: J15.4, U30.38
3.3V_EN15: J16.4, U32.38
3.3V_IN: D3.A, J2.2, J2.74
3.3V_IN1: D4.A, J1.2, J1.74
3.3V_IN2: D6.A, J3.2, J3.74
3.3V_IN3: D8.A, J4.2, J4.74
3.3V_IN4: D10.A, J5.2, J5.74
3.3V_IN5: D12.A, J6.2, J6.74
3.3V_IN6: D14.A, J7.2, J7.74
3.3V_IN7: D16.A, J8.2, J8.74
3.3V_IN8: D18.A, J9.2, J9.74
3.3V_IN9: D20.A, J10.2, J10.74
3.3V_IN10: D22.A, J11.2, J11.74
3.3V_IN11: D24.A, J12.2, J12.74
3.3V_IN12: D26.A, J13.2, J13.74
3.3V_IN13: D28.A, J14.2, J14.74
3.3V_IN14: D30.A, J15.2, J15.74
3.3V_IN15: D32.A, J16.2, J16.74
!CS: J2.55, U2.16
!CS1: J1.55, U4.16
!CS1!: R4.1, U1.1, U2.20
!CS1!1: R8.1, U3.1, U4.20
!CS1!2: R12.1, U5.1, U6.20
!CS1!3: R16.1, U7.1, U8.20
!CS1!4: R20.1, U9.1, U10.20
!CS1!5: R24.1, U11.1, U12.20
!CS1!6: R28.1, U13.1, U14.20
!CS1!7: R32.1, U15.1, U16.20
!CS1!8: R36.1, U17.1, U18.20
!CS1!9: R40.1, U19.1, U20.20
!CS1!10: R44.1, U21.1, U22.20
!CS1!11: R48.1, U23.1, U24.20
!CS1!12: R52.1, U25.1, U26.20
!CS1!13: R56.1, U27.1, U28.20
!CS1!14: R60.1, U29.1, U30.20
!CS1!15: R64.1, U31.1, U32.20
!CS2: J3.55, U6.16
!CS3: J4.55, U8.16
!CS4: J5.55, U10.16
!CS5: J6.55, U12.16
!CS6: J7.55, U14.16
!CS7: J8.55, U16.16
!CS8: J9.55, U18.16
!CS9: J10.55, U20.16
!CS10: J11.55, U22.16
!CS11: J12.55, U24.16
!CS12: J13.55, U26.16
!CS13: J14.55, U28.16
!CS14: J15.55, U30.16
!CS15: J16.55, U32.16
!HOLD!: U1.7, U2.50
!HOLD!1: U3.7, U4.50
!HOLD!2: U5.7, U6.50
!HOLD!3: U7.7, U8.50
!HOLD!4: U9.7, U10.50
!HOLD!5: U11.7, U12.50
!HOLD!6: U13.7, U14.50
!HOLD!7: U15.7, U16.50
!HOLD!8: U17.7, U18.50
!HOLD!9: U19.7, U20.50
!HOLD!10: U21.7, U22.50
!HOLD!11: U23.7, U24.50
!HOLD!12: U25.7, U26.50
!HOLD!13: U27.7, U28.50
!HOLD!14: U29.7, U30.50
!HOLD!15: U31.7, U32.50
!RESET: J2.6, R1.1, U2.52
!RESET1: J1.6, R5.1, U4.52
!RESET2: J3.6, R9.1, U6.52
!RESET3: J4.6, R13.1, U8.52
!RESET4: J5.6, R17.1, U10.52
!RESET5: J6.6, R21.1, U12.52
!RESET6: J7.6, R25.1, U14.52
!RESET7: J8.6, R29.1, U16.52
!RESET8: J9.6, R33.1, U18.52
!RESET9: J10.6, R37.1, U20.52
!RESET10: J11.6, R41.1, U22.52
!RESET11: J12.6, R45.1, U24.52
!RESET12: J13.6, R49.1, U26.52
!RESET13: J14.6, R53.1, U28.52
!RESET14: J15.6, R57.1, U30.52
!RESET15: J16.6, R61.1, U32.52
!WP!: U1.3, U2.49
!WP!1: U3.3, U4.49
!WP!2: U5.3, U6.49
!WP!3: U7.3, U8.49
!WP!4: U9.3, U10.49
!WP!5: U11.3, U12.49
!WP!6: U13.3, U14.49
!WP!7: U15.3, U16.49
!WP!8: U17.3, U18.49
!WP!9: U19.3, U20.49
!WP!10: U21.3, U22.49
!WP!11: U23.3, U24.49
!WP!12: U25.3, U26.49
!WP!13: U27.3, U28.49
!WP!14: U29.3, U30.49
!WP!15: U31.3, U32.49
A0/DAC: J2.34, U2.3
A0/DAC1: J1.34, U4.3
A0/DAC2: J3.34, U6.3
A0/DAC3: J4.34, U8.3
A0/DAC4: J5.34, U10.3
A0/DAC5: J6.34, U12.3
A0/DAC6: J7.34, U14.3
A0/DAC7: J8.34, U16.3
A0/DAC8: J9.34, U18.3
A0/DAC9: J10.34, U20.3
A0/DAC10: J11.34, U22.3
A0/DAC11: J12.34, U24.3
A0/DAC12: J13.34, U26.3
A0/DAC13: J14.34, U28.3
A0/DAC14: J15.34, U30.3
A0/DAC15: J16.34, U32.3
A1: J2.38, U2.61
A2: J1.38, U4.61
A2/PWM0: J2.32, U2.62
A2/PWM1: J1.32, U4.62
A2/PWM2: J3.32, U6.62
A2/PWM3: J4.32, U8.62
A2/PWM4: J5.32, U10.62
A2/PWM5: J6.32, U12.62
A2/PWM6: J7.32, U14.62
A2/PWM7: J8.32, U16.62
A2/PWM8: J9.32, U18.62
A2/PWM9: J10.32, U20.62
A2/PWM10: J11.32, U22.62
A2/PWM11: J12.32, U24.62
A2/PWM12: J13.32, U26.62
A2/PWM13: J14.32, U28.62
A2/PWM14: J15.32, U30.62
A2/PWM15: J16.32, U32.62
A3: J1.49, U4.64
A3/PWM1: J2.47, U2.63
A3/PWM2: J1.47, U4.63
A3/PWM3: J3.47, U6.63
A3/PWM4: J4.47, U8.63
A3/PWM5: J5.47, U10.63
A3/PWM6: J6.47, U12.63
A3/PWM7: J7.47, U14.63
A3/PWM8: J8.47, U16.63
A3/PWM9: J9.47, U18.63
A3/PWM10: J10.47, U20.63
A3/PWM11: J11.47, U22.63
A3/PWM12: J12.47, U24.63
A3/PWM13: J13.47, U26.63
A3/PWM14: J14.47, U28.63
A3/PWM15: J15.47, U30.63
A3/PWM16: J16.47, U32.63
A4: J2.49, U2.64
A5: J3.38, U6.61
A6: J3.49, U6.64
A7: J4.38, U8.61
A8: J4.49, U8.64
A9: J5.38, U10.61
A10: J5.49, U10.64
A11: J6.38, U12.61
A12: J6.49, U12.64
A13: J7.38, U14.61
A14: J7.49, U14.64
A15: J8.38, U16.61
A16: J8.49, U16.64
A17: J9.38, U18.61
A18: J9.49, U18.64
A19: J10.38, U20.61
A20: J10.49, U20.64
A21: J11.38, U22.61
A22: J11.49, U22.64
A23: J12.38, U24.61
A24: J12.49, U24.64
A25: J13.38, U26.61
A26: J13.49, U26.64
A27: J14.38, U28.61
A28: J14.49, U28.64
A29: J15.38, U30.61
A30: J15.49, U30.64
A31: J16.38, U32.61
A32: J16.49, U32.64
CIPO: J2.61, U2.15
CIPO1: U1.2, U2.19
CIPO2: J1.61, U4.15
CIPO3: U3.2, U4.19
CIPO4: J3.61, U6.15
CIPO5: U5.2, U6.19
CIPO6: J4.61, U8.15
CIPO7: U7.2, U8.19
CIPO8: J5.61, U10.15
CIPO9: U9.2, U10.19
CIPO10: J6.61, U12.15
CIPO11: U11.2, U12.19
CIPO12: J7.61, U14.15
CIPO13: U13.2, U14.19
CIPO14: J8.61, U16.15
CIPO15: U15.2, U16.19
CIPO16: J9.61, U18.15
CIPO17: U17.2, U18.19
CIPO18: J10.61, U20.15
CIPO19: U19.2, U20.19
CIPO20: J11.61, U22.15
CIPO21: U21.2, U22.19
CIPO22: J12.61, U24.15
CIPO23: U23.2, U24.19
CIPO24: J13.61, U26.15
CIPO25: U25.2, U26.19
CIPO26: J14.61, U28.15
CIPO27: U27.2, U28.19
CIPO28: J15.61, U30.15
CIPO29: U29.2, U30.19
CIPO30: J16.61, U32.15
CIPO31: U31.2, U32.19
COPI: J2.59, U2.13
COPI1: U1.5, U2.18
COPI2: J1.59, U4.13
COPI3: U3.5, U4.18
COPI4: J3.59, U6.13
COPI5: U5.5, U6.18
COPI6: J4.59, U8.13
COPI7: U7.5, U8.18
COPI8: J5.59, U10.13
COPI9: U9.5, U10.18
COPI10: J6.59, U12.13
COPI11: U11.5, U12.18
COPI12: J7.59, U14.13
COPI13: U13.5, U14.18
COPI14: J8.59, U16.13
COPI15: U15.5, U16.18
COPI16: J9.59, U18.13
COPI17: U17.5, U18.18
COPI18: J10.59, U20.13
COPI19: U19.5, U20.18
COPI20: J11.59, U22.13
COPI21: U21.5, U22.18
COPI22: J12.59, U24.13
COPI23: U23.5, U24.18
COPI24: J13.59, U26.13
COPI25: U25.5, U26.18
COPI26: J14.59, U28.13
COPI27: U27.5, U28.18
COPI28: J15.59, U30.13
COPI29: U29.5, U30.18
COPI30: J16.59, U32.13
COPI31: U31.5, U32.18
D0: J2.10, U2.5
D1: J2.18, U2.6
D2: R6.2, U4.44
D2/G0: J2.40, U2.9
D2/G1: J1.40, U4.9
D2/G2: J3.40, U6.9
D2/G3: J4.40, U8.9
D2/G4: J5.40, U10.9
D2/G5: J6.40, U12.9
D2/G6: J7.40, U14.9
D2/G7: J8.40, U16.9
D2/G8: J9.40, U18.9
D2/G9: J10.40, U20.9
D2/G10: J11.40, U22.9
D2/G11: J12.40, U24.9
D2/G12: J13.40, U26.9
D2/G13: J14.40, U28.9
D2/G14: J15.40, U30.9
D2/G15: J16.40, U32.9
D3: J1.10, U4.5
D3/G1: J2.42, U2.10
D3/G2: J1.42, U4.10
D3/G3: J3.42, U6.10
D3/G4: J4.42, U8.10
D3/G5: J5.42, U10.10
D3/G6: J6.42, U12.10
D3/G7: J7.42, U14.10
D3/G8: J8.42, U16.10
D3/G9: J9.42, U18.10
D3/G10: J10.42, U20.10
D3/G11: J11.42, U22.10
D3/G12: J12.42, U24.10
D3/G13: J13.42, U26.10
D3/G14: J14.42, U28.10
D3/G15: J15.42, U30.10
D3/G16: J16.42, U32.10
D4: J1.18, U4.6
D4/G1: J1.44, U4.11
D4/G2: J2.44, U2.11
D4/G3: J3.44, U6.11
D4/G4: J4.44, U8.11
D4/G5: J5.44, U10.11
D4/G6: J6.44, U12.11
D4/G7: J7.44, U14.11
D4/G8: J8.44, U16.11
D4/G9: J9.44, U18.11
D4/G10: J10.44, U20.11
D4/G11: J11.44, U22.11
D4/G12: J12.44, U24.11
D4/G13: J13.44, U26.11
D4/G14: J14.44, U28.11
D4/G15: J15.44, U30.11
D4/G16: J16.44, U32.11
D5: J1.43, U4.27
D5/G1: J1.46, U4.12
D5/G2: J3.46, U6.12
D5/G3: J2.46, U2.12
D5/G4: J4.46, U8.12
D5/G5: J5.46, U10.12
D5/G6: J6.46, U12.12
D5/G7: J7.46, U14.12
D5/G8: J8.46, U16.12
D5/G9: J9.46, U18.12
D5/G10: J10.46, U20.12
D5/G11: J11.46, U22.12
D5/G12: J12.46, U24.12
D5/G13: J13.46, U26.12
D5/G14: J14.46, U28.12
D5/G15: J15.46, U30.12
D5/G16: J16.46, U32.12
D6: J1.41, U4.28
D6/G1: J1.48, U4.23
D6/G2: J3.48, U6.23
D6/G3: J4.48, U8.23
D6/G4: J2.48, U2.23
D6/G5: J5.48, U10.23
D6/G6: J6.48, U12.23
D6/G7: J7.48, U14.23
D6/G8: J8.48, U16.23
D6/G9: J9.48, U18.23
D6/G10: J10.48, U20.23
D6/G11: J11.48, U22.23
D6/G12: J12.48, U24.23
D6/G13: J13.48, U26.23
D6/G14: J14.48, U28.23
D6/G15: J15.48, U30.23
D6/G16: J16.48, U32.23
D7: J1.67, U4.31
D7/G1: J1.73, U4.24
D7/G2: J3.73, U6.24
D7/G3: J4.73, U8.24
D7/G4: J5.73, U10.24
D7/G5: J2.73, U2.24
D7/G6: J6.73, U12.24
D7/G7: J7.73, U14.24
D7/G8: J8.73, U16.24
D7/G9: J9.73, U18.24
D7/G10: J10.73, U20.24
D7/G11: J11.73, U22.24
D7/G12: J12.73, U24.24
D7/G13: J13.73, U26.24
D7/G14: J14.73, U28.24
D7/G15: J15.73, U30.24
D7/G16: J16.73, U32.24
D8: J1.65, U4.32
D8/G1: J1.71, U4.25
D8/G2: J3.71, U6.25
D8/G3: J4.71, U8.25
D8/G4: J5.71, U10.25
D8/G5: J6.71, U12.25
D8/G6: J2.71, U2.25
D8/G7: J7.71, U14.25
D8/G8: J8.71, U16.25
D8/G9: J9.71, U18.25
D8/G10: J10.71, U20.25
D8/G11: J11.71, U22.25
D8/G12: J12.71, U24.25
D8/G13: J13.71, U26.25
D8/G14: J14.71, U28.25
D8/G15: J15.71, U30.25
D8/G16: J16.71, U32.25
D9: R10.2, U6.44
D9/G1: J1.69, U4.26
D9/G2: J3.69, U6.26
D9/G3: J4.69, U8.26
D9/G4: J5.69, U10.26
D9/G5: J6.69, U12.26
D9/G6: J7.69, U14.26
D9/G7: J2.69, U2.26
D9/G8: J8.69, U16.26
D9/G9: J9.69, U18.26
D9/G10: J10.69, U20.26
D9/G11: J11.69, U22.26
D9/G12: J12.69, U24.26
D9/G13: J13.69, U26.26
D9/G14: J14.69, U28.26
D9/G15: J15.69, U30.26
D9/G16: J16.69, U32.26
D10: J2.67, U2.31
D11: J2.65, U2.32
D12: J3.10, U6.5
D13: R3.2, U2.44
D14: J3.18, U6.6
D15: J3.43, U6.27
D16: J3.41, U6.28
D17: J3.67, U6.31
D18: J3.65, U6.32
D19: R14.2, U8.44
D20: J4.10, U8.5
D21: J4.18, U8.6
D22: J4.43, U8.27
D23: J4.41, U8.28
D24: J4.67, U8.31
D25: J4.65, U8.32
D26: R18.2, U10.44
D27: J5.10, U10.5
D28: J5.18, U10.6
D29: J5.43, U10.27
D30: J5.41, U10.28
D31: J5.67, U10.31
D32: J5.65, U10.32
D33: R22.2, U12.44
D34: J6.10, U12.5
D35: J6.18, U12.6
D36: J6.43, U12.27
D37: J6.41, U12.28
D38: J2.43, U2.27
D39: J2.41, U2.28
D40: J6.67, U12.31
D41: J6.65, U12.32
D42: R26.2, U14.44
D43: J7.10, U14.5
D44: J7.18, U14.6
D45: J7.43, U14.27
D46: J7.41, U14.28
D47: J7.67, U14.31
D48: J7.65, U14.32
D49: R30.2, U16.44
D50: J8.10, U16.5
D51: J8.18, U16.6
D52: J8.43, U16.27
D53: J8.41, U16.28
D54: J8.67, U16.31
D55: J8.65, U16.32
D56: R34.2, U18.44
D57: J9.10, U18.5
D58: J9.18, U18.6
D59: J9.43, U18.27
D60: J9.41, U18.28
D61: J9.67, U18.31
D62: J9.65, U18.32
D63: R38.2, U20.44
D64: J10.10, U20.5
D65: J10.18, U20.6
D66: J10.43, U20.27
D67: J10.41, U20.28
D68: J10.67, U20.31
D69: J10.65, U20.32
D70: R42.2, U22.44
D71: J11.10, U22.5
D72: J11.18, U22.6
D73: J11.43, U22.27
D74: J11.41, U22.28
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

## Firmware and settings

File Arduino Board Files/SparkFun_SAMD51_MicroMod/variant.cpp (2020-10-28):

/*
  Copyright (c) 2014-2015 Arduino LLC.  All right reserved.

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
  You should have received a copy of the GNU Lesser General Public
  License along with this library; if not, write to the Free Software
  Foundation, Inc., 51 Franklin St, Fifth Floor, Boston, MA  02110-1301  USA
*/

#include "variant.h"

// PIN DESCRIPTIONS
const PinDescription g_APinDescription[]=
{
  // Digital Pins
  // 0....16 
  // -------------------------------------------------------------------------------------------------------------------------
  { PORTB,  4, PIO_DIGITAL,   PIN_ATTR_NONE,  No_ADC_Channel, NOT_ON_PWM, NOT_ON_TIMER, EXTERNAL_INT_4 },  // D0
  { PORTB,  5, PIO_DIGITAL,   PIN_ATTR_NONE,  No_ADC_Channel, NOT_ON_PWM, NOT_ON_TIMER, EXTERNAL_INT_5 },  // D1 
  { PORTB,  6, PIO_DIGITAL,   PIN_ATTR_NONE,  No_ADC_Channel, NOT_ON_PWM, NOT_ON_TIMER, EXTERNAL_INT_6 },  // D2
  { PORTB,  7, PIO_DIGITAL,   PIN_ATTR_NONE,  No_ADC_Channel, NOT_ON_PWM, NOT_ON_TIMER, EXTERNAL_INT_7 },  // D3
  { PORTB,  8, PIO_DIGITAL,   PIN_ATTR_NONE,  No_ADC_Channel, TC4_CH0,    TC4_CH0,      EXTERNAL_INT_8 },  // D4
  { PORTB,  9, PIO_DIGITAL,   PIN_ATTR_NONE,  No_ADC_Channel, TC4_CH1,    TC4_CH1,      EXTERNAL_INT_9 },  // D5
  { PORTB, 10, PIO_DIGITAL,   PIN_ATTR_NONE,  No_ADC_Channel, NOT_ON_PWM, NOT_ON_TIMER, EXTERNAL_INT_10 }, // D6
  { PORTB, 11, PIO_DIGITAL,   PIN_ATTR_NONE,  No_ADC_Channel, NOT_ON_PWM, NOT_ON_TIMER, EXTERNAL_INT_11 }, // D7
  { PORTB, 12, PIO_DIGITAL,   PIN_ATTR_PWM_G, No_ADC_Channel, TCC3_CH0,   TC4_CH0,      EXTERNAL_INT_12 }, // D8
  { PORTB, 13, PIO_DIGITAL,   PIN_ATTR_PWM_G, No_ADC_Channel, NOT_ON_PWM, TC4_CH1,      EXTERNAL_INT_13 }, // D9
  { PORTA, 14, PIO_DIGITAL,   PIN_ATTR_PWM_G, No_ADC_Channel, NOT_ON_PWM, NOT_ON_TIMER, EXTERNAL_INT_14 }, // D10
  { PORTA, 15, PIO_DIGITAL,   PIN_ATTR_PWM_G, No_ADC_Channel, NOT_ON_PWM, NOT_ON_TIMER, EXTERNAL_INT_15 }, // D12
  { PORTA, 18, PIO_DIGITAL,   PIN_ATTR_PWM_F, No_ADC_Channel, TCC1_CH2,   TC3_CH0,      EXTERNAL_INT_2 },  // D12 - I2C_INT
  { PORTA, 23, PIO_DIGITAL,   PIN_ATTR_PWM_G, No_ADC_Channel, TCC1_CH3,   TC2_CH1,      EXTERNAL_INT_13 }, // D13
  { PORTA, 19, PIO_DIGITAL,   PIN_ATTR_NONE,  No_ADC_Channel, NOT_ON_PWM, NOT_ON_TIMER, EXTERNAL_INT_3 },  // D14 - 3.3V_EN
  { PORTB, 22, PIO_DIGITAL,   PIN_ATTR_NONE,  No_ADC_Channel, NOT_ON_PWM, NOT_ON_TIMER, EXTERNAL_INT_6 },  // D15 - FLASH WP
  { PORTB, 23, PIO_DIGITAL,   PIN_ATTR_NONE,  No_ADC_Channel, NOT_ON_PWM, NOT_ON_TIMER, EXTERNAL_INT_7 },  // D16 - FLASH HOLD
  // ------------------------------------------------------------------------------------------------------------------------- 
  
  // Analog Pins 
  // 17....27
  // ------------------------------------------------------------------------------------------------------------------------- 
  { PORTA,  2, PIO_ANALOG, PIN_ATTR_ANALOG,     ADC_Channel0,  NOT_ON_PWM, NOT_ON_TIMER, EXTERNAL_INT_2 },   // A0
  { PORTB,  0, PIO_ANALOG, PIN_ATTR_ANALOG,     ADC_Channel12, NOT_ON_PWM, NOT_ON_TIMER, EXTERNAL_INT_0 },   // A1
  { PORTB,  1, PIO_ANALOG, PIN_ATTR_ANALOG,     ADC_Channel13, NOT_ON_PWM, NOT_ON_TIMER, EXTERNAL_INT_1 },   // A2
  { PORTB,  2, PIO_ANALOG, PIN_ATTR_ANALOG,     ADC_Channel14, NOT_ON_PWM, NOT_ON_TIMER, EXTERNAL_INT_2 },   // A3
  { PORTB,  3, PIO_ANALOG, PIN_ATTR_ANALOG,     ADC_Channel15, NOT_ON_PWM, NOT_ON_TIMER, EXTERNAL_INT_3 },   // A4
  { PORTB,  4, PIO_ANALOG, PIN_ATTR_ANALOG_ALT, ADC_Channel6,  NOT_ON_PWM, NOT_ON_TIMER, EXTERNAL_INT_4 },   // A5
  { PORTB,  5, PIO_ANALOG, PIN_ATTR_ANALOG_ALT, ADC_Channel7,  NOT_ON_PWM, NOT_ON_TIMER, EXTERNAL_INT_5 },   // A6
  { PORTB,  6, PIO_ANALOG, PIN_ATTR_ANALOG_ALT, ADC_Channel8,  NOT_ON_PWM, NOT_ON_TIMER, EXTERNAL_INT_6 },   // A7
  { PORTB,  7, PIO_ANALOG, PIN_ATTR_ANALOG_ALT, ADC_Channel9,  NOT_ON_PWM, NOT_ON_TIMER, EXTERNAL_INT_7 },   // A8
  { PORTB,  8, PIO_ANALOG, PIN_ATTR_ANALOG,     ADC_Channel2,  TC4_CH0,    TC4_CH0,      EXTERNAL_INT_8 },   // A9
  { PORTB,  9, PIO_ANALOG, PIN_ATTR_ANALOG,     ADC_Channel3,  TC4_CH1,    TC4_CH1,      EXTERNAL_INT_9 },   // A10
  // -------------------------------------------------------------------------------------------------------------------------- 

  // DAC
  // 28
  // --------------------------------------------------------------------------------------------------------------- 
  { PORTA,  2, PIO_ANALOG, PIN_ATTR_ANALOG,  DAC_Channel0,  NOT_ON_PWM, NOT_ON_TIMER, EXTERNAL_INT_2 },      // DAC
  // --------------------------------------------------------------------------------------------------------------- 
 
  // USB/USB Host Enable
  // 29....31
  // --------------------------------------------------------------------------------------------------------------------
  { PORTA, 27, PIO_DIGITAL, PIN_ATTR_NONE, No_ADC_Channel, NOT_ON_PWM, NOT_ON_TIMER, EXTERNAL_INT_11 },      // USB HOST
  { PORTA, 24, PIO_COM,     PIN_ATTR_NONE, No_ADC_Channel, NOT_ON_PWM, NOT_ON_TIMER, EXTERNAL_INT_8 },       // USB DM
  { PORTA, 25, PIO_COM,     PIN_ATTR_NONE, No_ADC_Channel, NOT_ON_PWM, NOT_ON_TIMER, EXTERNAL_INT_9 },       // USB DP
  // ------------------------------------------------------------------------------------------------------------==-----

  // UART
  // 32..33
  // -----------------------------------------------------------------------------------------------------------------------
  { PORTB, 31, PIO_SERCOM_ALT, PIN_ATTR_NONE, No_ADC_Channel, NOT_ON_PWM, TC0_CH0, EXTERNAL_INT_15 },        // 5 SER1.0 TX
  { PORTB, 30, PIO_SERCOM_ALT, PIN_ATTR_NONE, No_ADC_Channel, NOT_ON_PWM, TC0_CH0, EXTERNAL_INT_14 },        // 6 SER1.1 RX
  // -----------------------------------------------------------------------------------------------------------------------
  
  // I2C pins (SDA/SCL)
  // 34..35
  // -----------------------------------------------------------------------------------------------------------------------
  { PORTA, 16, PIO_SERCOM_ALT, PIN_ATTR_PWM_F, No_ADC_Channel, TCC1_CH0, TC2_CH0, EXTERNAL_INT_0 },          // SCL  SER3.1
  { PORTA, 17, PIO_SERCOM_ALT, PIN_ATTR_PWM_G, No_ADC_Channel, TCC0_CH5, TC2_CH1, EXTERNAL_INT_1 },          // SDA  SER3.0
  // -----------------------------------------------------------------------------------------------------------------------
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

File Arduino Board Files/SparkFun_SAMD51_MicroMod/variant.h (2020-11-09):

/*
  Copyright (c) 2014-2015 Arduino LLC.  All right reserved.

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
  You should have received a copy of the GNU Lesser General Public
  License along with this library; if not, write to the Free Software
  Foundation, Inc., 51 Franklin St, Fifth Floor, Boston, MA  02110-1301  USA
*/

#ifndef _VARIANT_SAMD51_MICROMOD_
#define _VARIANT_SAMD51_MICROMOD_

// The definitions here needs a SAMD core >=1.6.10
#define ARDUINO_SAMD_VARIANT_COMPLIANCE 10610

//----------------------------------------------------------------------------
//        Definitions
//----------------------------------------------------------------------------

/** Frequency of the board main oscillator */
#define VARIANT_MAINOSC		(32768ul)

/** Master clock frequency */
#define VARIANT_MCK			  (120000000ul)

#define VARIANT_GCLK0_FREQ (120000000UL)
#define VARIANT_GCLK1_FREQ (48000000UL)
#define VARIANT_GCLK2_FREQ (100000000UL)

//----------------------------------------------------------------------------
//        Headers
//----------------------------------------------------------------------------

#include "WVariant.h"

#ifdef __cplusplus
#include "SERCOM.h"
#include "Uart.h"
#endif // __cplusplus

#ifdef __cplusplus
extern "C"
{
#endif // __cplusplus

//----------------------------------------------------------------------------
//        Pins
//----------------------------------------------------------------------------

// Number of pins defined in PinDescription array
#define PINS_COUNT           (53u)
#define NUM_DIGITAL_PINS     (16u)
#define NUM_ANALOG_INPUTS    (11u)
#define NUM_ANALOG_OUTPUTS   (1u)
#define analogInputToDigitalPin(p)  ((p < 6u) ? (p) + 14u : -1)

#define digitalPinToPort(P)        ( &(PORT->Group[g_APinDescription[P].ulPort]) )
#define digitalPinToBitMask(P)     ( 1 << g_APinDescription[P].ulPin )
//#define analogInPinToBit(P)        ( )
#define portOutputRegister(port)   ( &(port->OUT.reg) )
#define portInputRegister(port)    ( &(port->IN.reg) )
#define portModeRegister(port)     ( &(port->DIR.reg) )
#define digitalPinHasPWM(P)        ( g_APinDescription[P].ulPWMChannel != NOT_ON_PWM || g_APinDescription[P].ulTCChannel != NOT_ON_TIMER )

/*
 * digitalPinToTimer(..) is AVR-specific and is not defined for SAMD
 * architecture. If you need to check if a pin supports PWM you must
 * use digitalPinHasPWM(..).
 *
 * https://github.com/arduino/Arduino/issues/1833
 */
// #define digitalPinToTimer(P)

// General Purpose Pins
#define D0 0
#define D1 1
#define D2 2
#define D3 3
#define D4 4
#define D5 5

#define G0  2
#define G1  3
#define G2  4
#define G3  5
#define G4  6
#define G5  7
#define G6  8
#define G7  9
#define G8  10
#define G9  11
#define G11 29

#define PWM0 19
#define PWM1 20 

#define BATT_VIN 21 
#define POWER_CONTROL 12

#define CS 48 
#define CS1 52 
#define I2CINT 12

#define AUD_OUT 40
#define AUD_IN 41
#define AUD_BCLK 42
#define AUD_LRCLK 44
#define AUD_MCLK 43

// LEDs
//-------------------------------------------
#define PIN_LED_13           (13u)
#define PIN_LED              PIN_LED_13
#define LED_BUILTIN          PIN_LED_13
//-------------------------------------------

// Analog pins
//-------------------------------------------
#define PIN_A0               (17ul)
#define PIN_A1               (PIN_A0 + 1)
#define PIN_A2               (PIN_A0 + 2)
#define PIN_A3               (PIN_A0 + 4)
#define PIN_A4               (PIN_A0 + 5)
#define PIN_A5               (PIN_A0 + 6)
#define PIN_A6               (PIN_A0 + 7)
#define PIN_A7               (PIN_A0 + 8)
#define PIN_A8               (PIN_A0 + 9)
#define PIN_A9               (PIN_A0 + 10)
#define PIN_A10              (PIN_A0) 

//DAC
#define PIN_DAC0             PIN_A0

static const uint8_t A0   = PIN_A0;
static const uint8_t A1   = PIN_A0;
static const uint8_t A2   = PIN_A2;
static const uint8_t A3   = PIN_A3;
static const uint8_t A4   = PIN_A4;
static const uint8_t A5   = PIN_A5;
static const uint8_t A6   = PIN_A6;
static const uint8_t A7   = PIN_A7;
static const uint8_t A8   = PIN_A8;
static const uint8_t A9   = PIN_A9;
static const uint8_t A10  = PIN_A10;

static const uint8_t DAC0 = PIN_DAC0;

#define ADC_RESOLUTION		12
//-------------------------------------------

// Other pins
//-------------------------------------------
#define PIN_ATN              (53ul)
static const uint8_t ATN = PIN_ATN;
//-------------------------------------------

// Serial1 
//-------------------------------------------
#define PIN_SERIAL1_RX       (32ul)
#define PIN_SERIAL1_TX       (33ul)
#define PAD_SERIAL1_TX       (UART_TX_PAD_0)
#define PAD_SERIAL1_RX       (SERCOM_RX_PAD_1)
//-------------------------------------------

// SPI Interfaces
//-------------------------------------------
#define SPI_INTERFACES_COUNT 2
  
#define PIN_SPI_MOSI         (45u)
#define PIN_SPI_SCK          (46u)
#define PIN_SPI_MISO         (47u)
#define PIN_SPI_SS           (48u)
#define PERIPH_SPI           sercom0
#define PAD_SPI_TX           SPI_PAD_0_SCK_1
#define PAD_SPI_RX           SERCOM_RX_PAD_2

static const uint8_t SS	  = PIN_SPI_SS ;
static const uint8_t MOSI = PIN_SPI_MOSI ;
static const uint8_t MISO = PIN_SPI_MISO ;
static const uint8_t SCK  = PIN_SPI_SCK ;  

// SPI1
#define PIN_SPI1_MOSI         (49u)
#define PIN_SPI1_SCK          (50u)
#define PIN_SPI1_MISO         (51u)
#define PIN_SPI1_SS           (52u)
#define PERIPH_SPI1           sercom2
#define PAD_SPI1_TX           SPI_PAD_0_SCK_1
#define PAD_SPI1_RX           SERCOM_RX_PAD_2
//-------------------------------------------

static const uint8_t SS1	 = PIN_SPI1_SS ; 	
static const uint8_t MOSI1 = PIN_SPI1_MOSI ;
static const uint8_t MISO1 = PIN_SPI1_MISO ;
static const uint8_t SCK1  = PIN_SPI1_SCK ;

// Wire Interfaces
//-------------------------------------------
#define WIRE_INTERFACES_COUNT 2

#define PIN_WIRE_SCL         (34u)
#define PIN_WIRE_SDA         (35u)
#define PERIPH_WIRE          sercom3
#define WIRE_IT_HANDLER      SERCOM3_Handler
#define WIRE_IT_HANDLER_0    SERCOM3_0_Handler
#define WIRE_IT_HANDLER_1    SERCOM3_1_Handler
#define WIRE_IT_HANDLER_2    SERCOM3_2_Handler
#define WIRE_IT_HANDLER_3    SERCOM3_3_Handler

static const uint8_t SDA = PIN_WIRE_SDA;
static const uint8_t SCL = PIN_WIRE_SCL;

#define PIN_WIRE1_SCL         (36u)
#define PIN_WIRE1_SDA         (37u)
#define PERIPH_WIRE1          sercom4
#define WIRE1_IT_HANDLER      SERCOM4_Handler
#define WIRE1_IT_HANDLER_0    SERCOM4_0_Handler
#define WIRE1_IT_HANDLER_1    SERCOM4_1_Handler
#define WIRE1_IT_HANDLER_2    SERCOM4_2_Handler
#define WIRE1_IT_HANDLER_3    SERCOM4_3_Handler

static const uint8_t SDA1 = PIN_WIRE1_SDA;
static const uint8_t SCL1 = PIN_WIRE1_SCL;
//----------------------------------------------

// USB
//----------------------------------------------
#define PIN_USB_HOST_ENABLE (29ul)
#define PIN_USB_DM          (30ul)
#define PIN_USB_DP          (31ul)
//----------------------------------------------
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

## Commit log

2020-04-21 Renames files
    [MicroMod_SAMD51.brd, MicroMod_SAMD51.sch, SAMD51_Thing_Plus.brd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]
2020-04-21 Adds notes for quad spi, spi, and analog pins to schematic
    [MicroMod_SAMD51.brd, MicroMod_SAMD51.sch]
2020-04-22 Adds decoupling caps, adds I2S, and moves analog and digital pins
    [MicroMod_SAMD51.brd, MicroMod_SAMD51.sch]
2020-04-29 Fixes schematic - adds second i2c, adds additional digital pins, and adds PWM pins
    [MicroMod_SAMD51.brd, MicroMod_SAMD51.sch]
2020-04-30 Puts i2c on correct pin
    [MicroMod_SAMD51.brd, MicroMod_SAMD51.sch]
2020-04-30 Renumbers pins
    [MicroMod_SAMD51.brd, MicroMod_SAMD51.sch]
2020-04-30 Adds A3 to SAMD51, adds PWM to A2 and A3 net names
    [MicroMod_SAMD51.brd, MicroMod_SAMD51.sch]
2020-04-30 Corrects isolate on polygons, adds two other ground pours, and one power pour
    [MicroMod_SAMD51.brd]
2020-05-05 Trace routing for QSPI, and other SPI busses
    [MicroMod_SAMD51.brd]
2020-05-05 Updates Micro mod connector to latest version
    [MicroMod_SAMD51.brd, MicroMod_SAMD51.sch]
2020-05-06 More trace routing
    [MicroMod_SAMD51.brd, MicroMod_SAMD51.sch]
2020-05-07 Adds much better trace routing - rips up other routing
    [MicroMod_SAMD51.brd]
2020-05-07 Finishes trace routing
    [MicroMod_SAMD51.brd]
2020-05-07 Touch up on ground pour
    [MicroMod_SAMD51.brd]
2020-05-08 Cleans up trace routing
    [MicroMod_SAMD51.brd]
2020-05-08 Adds silk, cleans up schematic
    [MicroMod_SAMD51.brd, MicroMod_SAMD51.sch]
2020-05-09 Removes reset button
    [MicroMod_SAMD51.brd, MicroMod_SAMD51.sch]
2020-05-11 Updates processor board with new screw design
    [MicroMod_SAMD51.brd, MicroMod_SAMD51.sch]
2020-05-12 Updates symobl for SAMD51 to latest
    [MicroMod_SAMD51.brd, MicroMod_SAMD51.sch]
2020-05-19 Updates Design
    [MicroMod_SAMD51.brd, MicroMod_SAMD51.sch]
2020-05-19 Changes Ferrite bead to 0402, completes trace work since symbol for SAMD51 was recreated
    * Changes all parts to 0402 tight and fixes traces accordingly
    [MicroMod_SAMD51.brd, MicroMod_SAMD51.sch]
2020-05-20 Adds Differential ADC lines, battery voltage connection, 3.3V enable line
    * Also adds diode to prevent backpowering 3.3V line from RTC_3V
    [MicroMod_SAMD51.brd, MicroMod_SAMD51.sch]
2020-05-20 Adds gerbers of design
    [MicroMod_SAMD51.GBL, MicroMod_SAMD51.GBO, MicroMod_SAMD51.GBP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]
2020-05-21 Adds MicroMod logos
    [MicroMod_SAMD51.brd]
2020-05-21 Adds new gerbers to account for new silk
    [MicroMod_SAMD51.GBL, MicroMod_SAMD51.GBO, MicroMod_SAMD51.GTL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]
2020-05-21 Movers gerbers to production file
    [MicroMod_SAMD51.GBL, MicroMod_SAMD51.GBO, MicroMod_SAMD51.GBP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]
2020-05-21 Adds a testing carrier board so that I can test the functionality of the samd51
    [MicroMod-Testing-CarrierBoard.brd, MicroMod-Testing-CarrierBoard.sch]
2020-05-21 Finishes trace work on Test board - needs some silk
    [MicroMod-Testing-CarrierBoard.brd, MicroMod-Testing-CarrierBoard.sch]
2020-05-22 Adds silk to Testbed and moves SWD header
    [MicroMod-Testing-CarrierBoard.brd, MicroMod-Testing-CarrierBoard.sch]
2020-05-22 Updates silk on testing carrier board
    [MicroMod-Testing-CarrierBoard.brd, MicroMod-Testing-CarrierBoard.sch]
2020-05-22 Fixes very minor DRC errors
    [MicroMod-Testing-CarrierBoard.brd]
2020-05-27 Updates testing carrier board with all nets added and half of teh new ones added
    [MicroMod-Testing-CarrierBoard.brd, MicroMod-Testing-CarrierBoard.sch]
2020-05-27 Finishes routing board
    [MicroMod-Testing-CarrierBoard.brd]
2020-05-27 Adds labels to testing carrier board
    [MicroMod-Testing-CarrierBoard.brd]
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2020-06-25 Modifies about half of the variant.cpp file for
    [MicroMod_SAMD51.sch]
2020-07-21 Fills pin definitions in variants, fixes I2S and D13 which were swapped (I2S Bus was crossing IOSETs)
    [MicroMod_SAMD51.brd, MicroMod_SAMD51.sch]
2020-07-21 Adds pin numbering to variants.h, fixes comments in variants.cpp
    [variant.cpp, variant.h]
2020-07-30 Moves arduino files to a different folder, adds processor board to boards.txt
2020-08-05 Updates the CPP and .H file
    * Unfortunately it looks like I didn't do a symoblic link correctly and so I had to overwrite what was already in the repo. Mostly the small issues like incorrect pin numbering have been fixed.
    [blink_test.ino, variant.cpp, variant.h]
2020-08-07 Changes so that SPI and I2C work
    [MicroMod_SAMD51.brd, MicroMod_SAMD51.sch]
2020-08-13 Various testing elements in Variant files regarding Serial1 and Serial2
    * Changes old SPI naming convention to new one
    * Moves some pins around for more thought out layout (more details to come)
    [MicroMod_SAMD51.brd, MicroMod_SAMD51.sch]
2020-08-13 Begins routing, removes old
    [MicroMod_SAMD51.brd, MicroMod_SAMD51.sch]
2020-08-17 Adds routing to all but a few lines
    [MicroMod_SAMD51.brd]
2020-08-17 Finishing routing, and fixes minor DRC errors regarding wire stubs
    [MicroMod_SAMD51.brd]
2020-08-17 Updates SparkFun silk, rolls version to v11, fixes some traces that were not crossing others at 90 degrees.
    [MicroMod_SAMD51.brd, MicroMod_SAMD51.sch]
2020-08-20 Moves cap at top of board, adjusts USB differential pair
    [MicroMod_SAMD51.brd, MicroMod_SAMD51.sch]
2020-08-21 Increases dimension line width, fixes some proportional text, relabels A0 to includ DAC
    * Adds dimension measurements to measures layer
    [MicroMod_SAMD51.brd, MicroMod_SAMD51.sch]
2020-08-21 Adds voltage range to schematic
    [MicroMod_SAMD51.sch]
2020-08-24 Updates the variant boards to reflect the final SAMD51 hardware
    * QSPI was removed in place of a secondary SPI port
    * The digital pins were rearranged to allow for full bus transers
    * Analog pins were also consolidated
    * Testing on overlapping serial2 and I2C1 were removed
    * Text was cleaned up and arranged to look dapper or pretty depending on how you feel about it
2020-09-22 Correct mclk mask in bootloader
    [update-bootloader-sparkfun-samd51-micromod-v3.4.0-65-gdf89a1f-dirty.ino]
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2020-09-22 Updates the micromodd connector and swaps the SPI pins
    [MicroMod_SAMD51.brd, MicroMod_SAMD51.sch]
2020-09-22 Fixes LED pin in bootloader
    [update-bootloader-sparkfun-samd51-micromod-v3.4.0-65-gdf89a1f-dirty.ino]
2020-09-22 Fixes LED assignment in variant, routes SPI lines, rolls version to v12
    [MicroMod_SAMD51.brd, MicroMod_SAMD51.sch]
2020-09-23 Fixes SERCOM for Serial1
    [variant.cpp]
2020-09-23 Removes extra .uf2 files, puts config files into their own folder,
    * Small fixes to variant files - analog pin defines, sercom djustments, and WIRE+SPI counts
    [board_config.h, update-bootloader-sparkfun-samd51-micromod-v3.4.0-65-gdf89a1f-dirty.ino, variant.cpp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]
2020-09-23 v12 panel
    [MicroMod_SAMD51-Panel.brd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]
2020-09-23 fixes stray via
    [MicroMod_SAMD51.brd]
2020-09-23 v12 panel, take 2
    [MicroMod_SAMD51-Panel.brd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]
2020-09-23 ENIG note added to special instructions
    [MicroMod_SAMD51.brd]
2020-10-02 Updates SPI clock names to correct abbreviation
    [MicroMod_SAMD51.brd, MicroMod_SAMD51.sch]
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2020-10-21 Fixes typo in usbhost_D+ net
    [MicroMod_SAMD51.brd, MicroMod_SAMD51.sch]
2020-10-28 Updates CAN net names - CAN is not supported on SAM-"D" versions of the IC
    [MicroMod_SAMD51.brd, MicroMod_SAMD51.sch]
2020-11-04 Removes buzzard labels, test sketches, old carrier board, and adds preprocessors for General purpose pins
    [MicroMod-Testing-CarrierBoard.brd, MicroMod-Testing-CarrierBoard.sch]
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2021-09-14 Fixes swapped nets COPI/CIPO at flash chip
    [MicroMod_SAMD51.brd, MicroMod_SAMD51.sch]
2021-09-15 Updates to latest parts
    [MicroMod_SAMD51.brd, MicroMod_SAMD51.sch]
2021-09-15 Adds a few more vias, centers labels in schematic
    [MicroMod_SAMD51.brd, MicroMod_SAMD51.sch]
2021-09-16 Panel update
    [MicroMod_SAMD51-Panel.brd, MicroMod_SAMD51.brd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]
2021-12-16 Adds new panel
    * To generate this panel I simply deleted everything but the board file, then I appended v13 to the name.
    * I then used the CAMMER ulp to remake the gerbers.
    [MicroMod_SAMD51-Panel_v13.GBL, MicroMod_SAMD51-Panel_v13.GBO, MicroMod_SAMD51-Panel_v13.GBP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]

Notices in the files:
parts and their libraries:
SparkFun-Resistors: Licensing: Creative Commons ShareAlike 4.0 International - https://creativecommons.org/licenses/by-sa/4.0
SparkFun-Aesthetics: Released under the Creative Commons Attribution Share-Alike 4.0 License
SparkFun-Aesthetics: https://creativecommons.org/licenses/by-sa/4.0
